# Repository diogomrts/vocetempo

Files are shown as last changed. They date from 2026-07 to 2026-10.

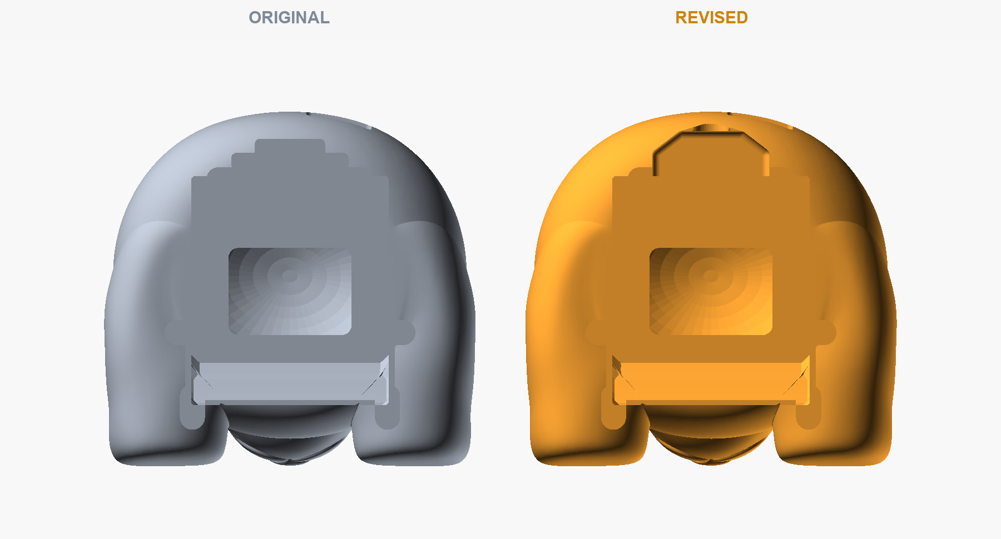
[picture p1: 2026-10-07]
enclosure/previews/joystick_bottom_views.png

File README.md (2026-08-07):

# Vocetempo

A standalone **talking bedside clock** built on an ESP32. It works completely
offline — no Wi-Fi, Bluetooth, internet, or phone required. It shows the time
on an OLED and speaks it aloud, automatically at configurable intervals or
on demand with a button.

> The name blends Italian _voce_ (voice) with _tempo_ (time), rooted in the
> Latin _vox_ + _tempus_.

## Features (v1)

- Large clock display (HH:MM), date, and weekday on a 2.42" OLED.
- Spoken time on demand and automatically (hourly / 30 min / 15 min).
- Single-thumbstick control, so the whole UI can be found by feel in the dark.
- Quiet hours: silence automatic announcements overnight (manual still works).
- Automatic daylight saving: pick your region once and the clock adjusts itself
  twice a year, entirely offline. Off by default.
- Fully on-device configuration; settings persist in flash.
- Modular speech clips for compact storage and easy future languages.

## Daylight saving

Under **Settings → Summer time**, choosing a region makes the clock change
itself on the right night, with no internet and nothing to maintain: every
region below switches on an algorithmic rule ("last Sunday in March"), so the
dates are computed on-device and stay correct indefinitely.

| Setting | Region |
| --- | --- |
| `Off` | no daylight saving (default) |
| `UK/Portugal`  | UK, Ireland, Portugal, Canary Islands |
| `Europe CET` | Spain, France, Germany, Italy, Poland, … |
| `Europe EET` | Greece, Finland, Romania, the Baltics |
| `USA/Canada` | all US and Canadian zones |
| `Chile` | Chile |
| `Australia SE` | NSW, Victoria, South Australia, Tasmania, ACT |
| `New Zealand`  | New Zealand |

Leave it `Off` for anywhere that no longer observes DST, including Brazil,
Argentina, most of Mexico, Russia, Turkey, India, China and Japan.

Choosing a region never changes the time on screen — only what happens on the
transition nights from then on. It can be set at any point, before or after
setting the clock, and in any month.

Internally the DS3231 stores **standard (winter) time** and is never rewritten
for a transition, so the hardware keeps ticking undisturbed; the offset is
applied when the time is read.

## Hardware

- DollaTek ESP32 dev board (ESP-WROOM-32, CP2102, USB-C)
- Hailege 2.42" SSD1309 128x64 OLED (I2C)
- DollaTek DS3231 RTC (I2C)
- DFPlayer Mini + microSDHC (audio)
- CQRobot 3W 4ohm speaker
- KY-023 analog joystick (up/down, left = back, right or click = OK)
- 5V USB wall power

See [`docs/PLAN.md`](docs/PLAN.md) for the staged roadmap,
[`docs/WIRING.md`](docs/WIRING.md) for the pin-by-pin wiring, and
[`docs/ASSEMBLY.md`](docs/ASSEMBLY.md) for soldering and enclosure assembly.

## Toolchain

- [PlatformIO](https://platformio.org/) with the Arduino framework for ESP32.
- Board environment: `esp32dev`.

## Build & upload

```sh
# Build
pio run

# Upload to the connected board
pio run --target upload

# Open the serial monitor (115200 baud)
pio device monitor

# Run the unit tests on your computer (no board required)
pio test -e native
```

The `native` test environment builds only the hardware-free logic — the
daylight-saving rules and the announcement scheduler — so both can be verified
on the host without waiting for a transition night.

## Status

**Stage 1 of 12** — verifying ESP32 programming with a serial "Hello"
heartbeat and onboard LED blink. Hardware peripherals are added one stage at a
time; see the roadmap in `docs/PLAN.md`.

## License

MIT — see [`LICENSE`](LICENSE).

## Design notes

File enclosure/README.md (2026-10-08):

# Vocetempo enclosure

Parametric 3D-printable enclosure for the panda-themed talking clock, written in
[OpenSCAD](https://openscad.org). The electronics live in a **slide-out cage**
that drops into a hollowed panda figurine from below, so the panda never has to
be opened to service the clock.

**Current body: v8, 217.4 mm tall (108.7% of the original sculpt).** The cage,
cavity and hardware cuts remain at their original size and position. Use the
new `joy_cap_scaled_body.stl` with this body; the original cap is too short.
Print the exports at **100% in the slicer** — do not scale the completed STL.

The latest two-colour version is
[`3mf/panda_colored_final.3mf`](3mf/panda_colored_final.3mf).
The saved [`full` project](3mf/panda_body_uniform_v8_black_white_full.3mf) has
identical geometry and painting; the final file packages its mesh in one model entry.
Open it **as a project** in Bambu Studio / OrcaSlicer to retain the painting:
filament 1 is white and filament 2 is black. Select your actual printer, material
and print profiles before slicing; the file is an unsliced painted model.
The original 500,162 triangles and all v8 cutouts are unchanged. Black covers
the ears, eye patches/eyes, nose, arms/shoulder band and feet. The colour data
survived a Bambu Studio 2.8.2.61 import/export check without changes.
The complete surface revision wraps the black feet around both full soles,
connects both arms continuously into the back band, and paints the ear vent bore
walls black. Fine paint boundaries follow the sculpted seams. The internal cage
and mounting surfaces remain white; the physical mesh is unchanged.
See the [six-angle full-body preview](previews/panda_body_v8_paint_full_views.png),
[360-degree view](previews/panda_body_v8_paint_full_turntable.gif),
[underside and arm comparison](previews/panda_body_v8_paint_full_comparison.png),
and [original painting report](previews/panda_body_v8_paint_full_checks.txt).
The latest saved projects include additional paint touch-ups on 3,796 triangles;
they preserve the approved v8 geometry within native-save rounding (under 0.0001 mm).
See the [saved-project audit](previews/panda_body_v8_saved_projects_checks.txt)
for current file hashes and the final Bambu Studio round-trip check.
The [previous precision painting](3mf/panda_body_uniform_v8_black_white_precision.3mf),
[detailed painting](3mf/panda_body_uniform_v8_black_white_detailed.3mf), and
[first painted version](3mf/panda_body_uniform_v8_black_white.3mf) are retained.

## Files

| File | Purpose |
| ---- | --- |
| `dimensions.scad` | Every component measurement + design decision, in ONE place. **Edit here.** |
| `helpers.scad` | Shared shape modules (rounded box, screw boss, etc.). |
| `cage.scad` | The electronics cage - the real mechanical part. Print-ready. |
| `panda.scad` | The panda body: uniformly enlarges the original sculpt, then applies fixed-size hardware cuts. |
| `expand_rump.py` | Historical v5 local deformation generator; no longer used by the current body. |
| `fitcheck.scad` | Seats the cage in the body (ghost / section / breach modes). |
| `layout_walls.scad` | 2D map of all four mounting walls, unrolled (collision check). Includes `cage.scad`, so it cannot drift from the geometry. |
| `render_previews.sh` | Renders `previews/*.png`. |
| `verify_window.py` | Blender check: pixel coverage of the OLED window + exactly where its cut lands on the sculpt. Run it after touching `oled_win_*`. |
| `verify_cage.py` | Ray-casts the exported cage and asserts every mount is real: bosses on flat wall, OLED envelope clear, joystick standoffs proud of the back wall, base open, cover ledge present. Run it after touching any mount. |
| `verify_joystick_channel.py` | Checks the exported body against the printed cage, the joystick's full insertion sweep (including bare shaft and bent header), and the remaining rear wall. |
| `verify_entrance.py` | Checks the entrance against 353 cage positions and verifies that the local repair preserves the rest of the body and magnet supports. Reports higher corner interference separately. |
| `verify_rear_cover.py` | Historical v4/v5 rear-cover checks; not applicable to the uniformly scaled v6/v7 bodies. |
| `verify_assembly_alignment.py` | Audits actual OLED sight lines, speaker aperture/connected sound path/all 26 ear vents, USB alignment, unchanged cage geometry and the v8 internal-only correction. |
| `verify_uniform_body.py` | Checks exact uniform scaling, fixed hardware clearances, magnet supports, cage insertion and the longer cap at both PCB spacings/socket orientations. |
| `probe_skin.py` | Where the sculpt's belly surface is at any (X, Z). |
| `probe_env.py` | Belly / rump / half-width envelope per height - how big a box fits. |
| `fit_shell.py` | **Solves** `shell_prof` against the sculpt. Re-run after changing `cage_w`, `cage_d`, `cage_yfront`, `cage_z0` or `cage_h`. |
| `refit.py` | Derives EVERY host-dependent constant in one pass - the transform, `shell_prof`, the OLED and joystick placements, the head/neck/ear survey, the magnet check. Run it after swapping the sculpt or resizing the box. |
| `scale_sweep.py` | Host height vs every gate. This is the table that chose 200 mm. |
| `compare_mesh.py` | Diffs two sculpts (size, shape, where the surfaces moved). |

The Python tools need `numpy` (`verify_window.py` needs Blender). Every tool
reproduces `panda_raw()`'s frame exactly, so their numbers paste straight into
`dimensions.scad`.

## The cage (`cage.scad`)

A box, 75 (W) x 80 (H) x 88 (D) mm, open at the base (the "service side").
Its cross-section (defined by `shell_prof` in `dimensions.scad`) is a rectangle
whose FRONT FACE can be set back per height and whose CORNERS can be chamfered per
height. It stays flat, full and forward through the whole board-mounting zone - so
every module's bosses land on a real, flat wall - and only moves where there are no
features: the base fillet, the paw crests, and the shoulders. That is how it follows
the round panda without either spearing its corners through the skin OR moving the
walls away from the mounting bosses. On this host the `breach` fit-check renders
**completely empty**, and the cage-inside-body collision check has zero volume.

- **Front face:** the OLED window (the true 55 x 28 lit area, offset +3.1 mm up)
  and **nothing else**. The PCB is 68.63 x 46.60 and even 88 mm of depth does not
  make room for a second device on this wall.
- **Back wall:** the **joystick**, bolted to four standoffs on the wall's OUTER
  face; the DFPlayer lower-right and the USB-C exit slot lower-left, inside.
- **Side walls:** ESP32 (left, portrait, USB-C edge down); RTC (right, on its 3
  real holes). The corner chamfers never cut a side face (`cf` peaks at 1.92), so
  a side wall is full-depth through the whole board zone.
- **Top face:** stadium-shaped throat firing UP into the panda's head (the head
  is the acoustic resonator); four bosses for the boxed speaker's ears.
- **Base:** an outward flange with 4 magnet pockets (retains the cage in the
  body), a ledge round the inside of the walls, and a screw-on **base cover**.

### The joystick bolts to the OUTSIDE of the back wall

It is on the rump, not the belly: the OLED alone is 46.6 mm tall and the KY-023
adds another 26.7 plus clearance, which no front wall this sculpt offers can hold.

*How* it mounts changed with the re-fit. It used to drop into a pocket in a
thickened plinth inside the back wall, with the gimbal poking out through a bore and
a separate printed frame clamping the PCB down - all of that existed because the
module's own mounting holes (19.85 x 19.80) sit right on the edge of the bore the
gimbal (19.80 x 23.40) needs, so a boss there loses over half its section.

Turning the module round deletes the problem. With the PCB on standoffs on the
wall's OUTER face and the gimbal pointing away into the rump there is no bore, no
pocket, no plinth and no frame; the only thing that crosses the wall is five wires.
It also uses the module's own four holes, which is what they are for. Fit it before
the cage goes into the panda - the screws come from the rump side.

The cost is depth. Measured out from the cage's back face at panda Y-43:

```
 2.00  standoff
 0.92  PCB
11.76  gimbal body
14.68  proud of the wall  (the rump is 25.7 mm deep here, leaving 11.0 for the cap)
```

The rump has a **continuous insertion channel**, wide enough for the PCB and bent
header near the cage and narrowing toward the gimbal. The printed **stalk cap**
spans the remaining 11 mm to the surface and is fitted only after insertion.

### Assembly relief v2, 2026-10-07

The physical assembly needs more room than the original nominal clearance check
suggested. The joystick is mounted sideways, and the **left side when looking
straight into the panda's back** needs the deeper recess all the way across.
That side is **panda -X**. The first comparison's simplified hardware overlay
omitted the side projection and assumed the recorded 2 mm PCB stand-off; it must
not be used as a measurement of the assembled device.

The v2 body adds another **3 mm of depth beyond the first relief**, keeps the
channel **10 mm taller than the original**, and preserves the printed cage,
cover, cap bore, magnet seats and mounting locations:

- Main gimbal limit **Y-64.5**: **21.5 mm behind the cage wall**, 6 mm deeper than
  the original channel and 3 mm deeper than v1.
- PCB/header shoulders also gain **another 3 mm**, to Y-51 and Y-57.5.
- Bare-shaft groove **Y-67.43**: **24.43 mm behind the cage wall**, another 3 mm
  beyond v1. This allows 3 mm extra PCB spacing while keeping 0.8 mm beyond the
  recorded shaft tip.
- A **broad left recess** extends to X-22.9 and Y-64.5 through Z55. Above that it
  slopes inward with the narrowing rear skin and joins the **3 mm rounded roof**
  at Z75.35. Its 2 mm side corner radii avoid sharp notch corners.
- The continuous underside opening reaches approximately **Z19.2 mm**. The wall
  tapers above the opening; over Z25..75.35 the 0.5 mm inspection grid measured a
  minimum **1.06 mm** to the outside skin. The USB and cap holes are excluded.
  The user explicitly accepted a thinner rear wall for this clearance revision.

The export is one closed, consistently oriented solid. Checks pass for the
printed cage and the full insertion sweep with **3 mm extra PCB stand-off**, both
in-plane PCB/gimbal orientations, the bare shaft, both header directions and an
additional bulky left-side allowance. No unintended rear openings were found
above the entrance. These are geometric allowances, not confirmation of the
unmeasured assembly or a material-strength simulation.

Check the preserved v2 export from this directory:

```sh
# Requires numpy, trimesh, manifold3d, scipy and rtree:
python verify_joystick_channel.py stl/panda_body_joystick_relief_v2.stl
```

`stl/panda_body_joystick_relief_v2.stl` preserves the approved joystick revision.
The latest body adds the entrance fix and smooth rump expansion below. The original and first relief are
retained in `stl/previous/`.
See `previews/joystick_bottom_comparison_v2.png` for the actual channel profiles;
the blue line marks v1. Earlier comparison images are historical v1 views.

### Entrance relief v3, 2026-10-07

The printed cage caught a sharp lip between the feet. The old body cavity copied
the cage's narrowed base section, even though the wider upper cage wall must pass
that same height. At Z7.1 the lip projected about **1.8 mm into the insertion
path**. V3 removes it and adds a front-only **0.8 mm lead-in bevel**, tapering to
the existing front clearance at the flange seat, Z11.2.

Only 0.381 cm³ is removed, entirely within the front entrance below Z11.25.
The magnet pockets/supports, flange seat, OLED opening and joystick v2 geometry
are unchanged; none of the already-printed cage parts needs replacing. The
export is one closed solid. At 353 cage positions spaced 0.25 mm apart, entrance
overlap falls from 103.588 mm³ to zero. The seated cage and all joystick checks
also pass. See `previews/entrance_comparison_v3.png` and the accompanying check
reports.

**Scope limit:** the higher corner ridges beside the paws remain. Removing their
entire insertion envelope would open holes in the outer wall. A perfectly
straight full-body insertion still has up to 5.777 mm³ overlap there, unchanged
by this local repair. V3 fixes the reported entrance obstruction; it is not a
guarantee of a completely interference-free physical assembly.

`stl/panda_body_entrance_relief_v3.stl` preserves this revision for comparison.

```sh
python verify_entrance.py stl/panda_body_entrance_relief_v3.stl --baseline stl/panda_body_joystick_relief_v2.stl
```

### Reduced uniform enlargement v7, 2026-10-08

V7 reduces the body enlargement from **15% to 8.7%**, keeping the whole original
sculpt uniformly scaled about the ground-plane origin. Its round proportions are
unchanged. Overall size is **157.280 × 150.182 × 217.4 mm (W/D/H)**, down from
166.396 × 158.886 × 230 mm in v6. `panda_body_scale` controls only the body blank;
`panda_h`, `panda_raw()` and the original skin reference stay at 200 mm for the
already-printed cage and base cover.

**The lower-left notch corner sets the minimum scale.** With the fixed notch and
original outside shape, 108.7% leaves a minimum sampled wall of **1.019 mm** above
the underside flange seat at Z11.2. At 108.6% it drops to 0.976 mm. This is the
smallest tested scale in 0.1% increments that retains a 1 mm wall there. The
nearest-surface check covers 20,836 points, with 0.05 mm spacing along the limiting
lower edge; intentional USB and cap openings are excluded. This is a geometric
thickness measurement, not a material-strength guarantee. The wall higher up is
thicker because the unchanged notch and original outer curve are different
shapes; above Z25 its minimum is 6.667 mm, reduced from 10.538 mm in v6.

The cage cavity, v2 deep left joystick channel, v3 entrance lead-in, screen window,
14 mm cap bore, USB cutter, flange seat and magnet pockets keep their sizes and
coordinates. The sound chamber and ear vents follow the enlarged head; overlapping
original/scaled chimney sections join them to the fixed speaker position. The
screen is more recessed than on the original body, but less than in v6. The
underside remains open for cage insertion.

**Reprint the body and the matching `joy_cap_scaled_body` cap.** The back at the
cap centre is now 6.18 mm farther out than the original. The v7 cap has a **20 mm
stalk and 4 mm neck**, shortened from v6's 24 mm stalk; it retains the same keyed
socket and 16 mm thumb pad. It clears the unchanged bore in both socket
orientations, nominal and +3 mm PCB spacing, 0–11° tilt in 15° azimuth increments
(1,152 poses), also with a 10% radial size allowance. Print the neck solid and
check fit/movement before gluing. The cage, cover and retention bars are unchanged.

Validation: one connected closed body; the blank exactly matches the uniformly
scaled original; all fixed hardware cutters are clear; all four magnet supports
remain intact. The cage seats without collision and the repaired feet entrance
clears at 353 insertion positions. The existing **5.777 mm³ higher front-corner
interference remains**, so this is not a physical friction-free fit certification.
The PCB, sideways gimbal, bare shaft and both header orientations pass the existing
insertion-envelope checks, including the requested extra 3 mm PCB spacing.

**Latest body: `stl/panda_body_uniform_v8.stl`.** `panda_body.stl` and
`panda_body_joystick_relief.stl` are identical copies. The matching cap is
`stl/joy_cap_uniform_v7.stl`, also copied to `joy_cap_scaled_body.stl`.
`stl/Archive.zip` contains the current body, matching cap, unchanged cage/cover/bars
and printing notes. Slice these at **100%** to preserve the unscaled cavity;
217.4 mm usable print height is needed, plus any raft.

See `previews/uniform_body_comparison_v7.png` for original/v6/v7 size comparison
and `previews/uniform_body_section_v7.png` for the thinner rear-wall section.
Reports are `previews/uniform_body_v7_*checks.txt`.

```sh
# OpenSCAD Manifold; Python checks need numpy/trimesh/manifold3d/scipy/rtree.
openscad --backend=Manifold --export-format binstl -o stl/panda_body.stl panda.scad
openscad --backend=Manifold -D 'part="joy_cap_scaled_body"' -o stl/joy_cap_scaled_body.stl cage.scad
openscad --backend=Manifold -D 'mode="body_blank"' -o /tmp/blank.stl fitcheck.scad
openscad --backend=Manifold -D 'mode="hardware_void"' -o /tmp/hardware_void.stl fitcheck.scad
openscad --backend=Manifold -D 'mode="joystick_void"' -o /tmp/channel.stl fitcheck.scad
openscad --backend=Manifold -D 'mode="usb_void"' -o /tmp/usb.stl fitcheck.scad
python verify_uniform_body.py stl/panda_body.stl --scale 1.087 --channel /tmp/channel.stl --usb /tmp/usb.stl --blank /tmp/blank.stl --hardware-void /tmp/hardware_void.stl --cap stl/joy_cap_scaled_body.stl --baseline stl/panda_body_entrance_relief_v3.stl
python verify_joystick_channel.py stl/panda_body.stl --skin /tmp/blank.stl
```

Previous versioned bodies, caps and previews are retained for comparison. V4's
cover and v5's local rump deformation were rejected aesthetically; v6's uniform
115% enlargement was too large. The v5 generator/source pair is no longer used
by `panda.scad`. The original `joy_cap` remains available for 200 mm bodies.
Print exports and ZIPs stay local under the existing ignore rule.

### Assembly alignment audit / speaker inlet v8, 2026-10-08

V8 keeps v7's **108.7% sculpt, 217.4 mm height, 1.019 mm minimum notch wall,
fixed cage cavity and same cap**. A full export audit found that the speaker's
cage opening is centred at panda Y-7 (the cage speaker is shifted 8 mm), while
the neck chimney is centred near Y1. A 3.208 mm rear strip of the throat therefore
met body material immediately above the cage roof: 142.541 mm³ of obstruction
inside the exported throat cutter.

`panda_speaker_inlet()` now clears the whole opening through the roof and blends
it into the existing neck chimney. The speaker offset is shared in
`dimensions.scad` so the two parts cannot drift. It removes **580.715 mm³** of
internal plastic; the change stays at least **37.938 mm inside the outer skin**.
Nothing is added, and no external shape, electronics placement, magnet seat,
OLED/joystick/USB cut or cage geometry changes. The printed cage and v7 cap remain
usable; the body is the only updated print file.

The audit verifies:

- Current cage source versus already-printed `cage.stl`: **zero geometric change**.
  OLED, speaker and joystick bosses/pilots, base ledge and side-board mounts pass
  `verify_cage.py`.
- OLED: 55.4 × 28.4 mm body opening, centred X0/Z47.8; all 8,192 pixel sight lines
  clear the cage. The body shows **8,188**, with the same four extreme corner
  pixels masked by its original 2 mm corner radii.
- Speaker: full offset cage throat clear, connected inlet/chimney/head chamber,
  **all 26 ear vents open to the exterior**. Acoustic loudness/resonance has not
  been measured on a physical print.
- Joystick: fixed 14 mm bore at X0/Z50; sideways PCB/gimbal/header and bare-shaft
  insertion envelopes pass, including +3 mm PCB spacing and the deep left recess.
  The unchanged v7 20 mm cap passes all **1,152** movement poses.
- USB: both body and cage slots clear all **589** access-ray samples.
- Cage seating, four magnet supports, thin notch wall and repaired entrance still
  pass. The existing higher front-corner insertion interference remains unchanged.

Reports: `previews/assembly_v8_checks.txt`, `assembly_v8_cage_checks.txt`,
`assembly_v8_uniform_checks.txt` and `assembly_v8_joystick_checks.txt`.

```sh
openscad --backend=Manifold -D 'part="cage"' -o /tmp/cage-current.stl cage.scad
openscad --backend=Manifold -D 'mode="speaker_void"' -o /tmp/speaker.stl fitcheck.scad
openscad --backend=Manifold -D 'mode="speaker_inlet"' -o /tmp/inlet.stl fitcheck.scad
openscad --backend=Manifold -D 'mode="acoustic_void"' -o /tmp/acoustic.stl fitcheck.scad
python verify_cage.py stl/cage.stl
# /tmp/blank.stl comes from the body_blank export above.
python verify_assembly_alignment.py stl/panda_body.stl --baseline stl/panda_body_uniform_v7.stl --blank /tmp/blank.stl --cage-source /tmp/cage-current.stl --speaker /tmp/speaker.stl --acoustic /tmp/acoustic.stl --inlet /tmp/inlet.stl
```

### Printable parts (via the `part` selector at the bottom of `cage.scad`)

```sh
openscad --backend=Manifold -o stl/cage.stl      -D 'part="cage"'      cage.scad
openscad --backend=Manifold -o stl/cover.stl     -D 'part="cover"'     cage.scad
openscad -o stl/esp32_bar.stl -D 'part="esp32_bar"' cage.scad
openscad -o stl/dfp_bar.stl   -D 'part="dfp_bar"'   cage.scad
openscad -o stl/joy_cap_scaled_body.stl -D 'part="joy_cap_scaled_body"' cage.scad # current 217.4mm body
openscad -o stl/joy_cap.stl -D 'part="joy_cap"' cage.scad # historical 200mm body only
```

`cage` and `cover` need **Manifold**: both clip themselves to the panda mesh (the
cage's upper shell to the eroded skin, the cover to the sculpt's domed base). There
is no `joy_frame` any more.

Then check it:

```sh
python verify_cage.py stl/cage.stl
```

## Original 200 mm reference and design history

The following measurements describe the **200 mm reference used by the cage**.
The current v8 outer body is separately enlarged to 217.4 mm as described above.

`panda/panda_original_without_embosses.stl` removes the sculpt's embossed screen
plaque and belly knob, so openings no longer have to land on a sculpted feature.
It is the host, at **200 mm** tall. Both changes landed together, because they had
to: the replacement is a different size and shape, not the same mesh with two bumps
shaved off, and at 160 mm it did not fit the electronics at all.

| | old | de-embossed |
| --- | --- | --- |
| raw Z span | 0.95893 | 0.93937 (2% shorter) |
| raw Y span | 0.70079 | 0.64892 (7% shallower) |
| raw X | 0.44 mm off-centre | symmetric |
| belly @ the screen, X0 | plaque | smooth, no feature to key off |

The transform is now **derived from the mesh** rather than hand-fitted, so swapping
the sculpt again changes two constants instead of the whole design:

```
panda_scale   212.9096      (= 200 / 0.93937 raw Z span; was a hand-fitted 166.7)
panda_y_off     9.036       (was a hand-fitted 26)
panda_x_off     0           (this mesh is symmetric)
```

`refit.py` prints the entire constant set for a given host in one pass, and every
number in `dimensions.scad` that depends on the sculpt came from it.

### What 200 mm buys, and what it does not

The parts do not scale - a 2.42" OLED is 68.63 x 46.60 whatever size the panda is -
so the host's size *is* the clearance budget. `scale_sweep.py` sweeps it:

```
panda_h | yfront | cage_d | plate band (cage Z) | top setback | recess | rump
    160 |   36.0 |   70.4 |   2.0.. 32.0 =  30.0 !|      7.9   |   12.6 |  19.9
    180 |   40.5 |   79.2 |   2.0.. 36.0 =  34.0 !|     17.9   |   14.4 |  22.8
    190 |   42.8 |   83.6 |   2.0.. 38.0 =  36.0 !|     19.8   |   15.2 |  24.2
    200 |   45.0 |   88.0 |   2.0.. 62.0 =  60.0  |     16.2   |   15.7 |  25.7
    210 |   47.2 |   92.4 |   2.0.. 66.0 =  64.0  |     12.7   |   16.1 |  27.1
! = the front plate is shorter than the OLED's 46.6mm PCB, so the screen cannot mount
```

200 is the smallest host where the front plate is long enough to hang the screen on.
Below it the plate collapses to ~30-36 mm against the 46.6 the PCB needs.

It also unpicks the deadlock that stopped the re-fit landing for a session. At 160
`cage_h` had exactly one legal value with 0.8 mm to spare - the belly pinched at
panda Z72, capping it at 64, against the 61.2 mm (`cover_ledge_h` 6 + margin 2 +
`esp_w` 53.2) a portrait ESP32 needs - and at that height the ESP32's USB-C mouth
landed on the cover ledge, so a straight plug was impossible and the panel-mount
port became mandatory. At 200 the box is 80 tall, the interior is 78, and
`6 + 2 + 16 (straight plug) + 53.2 = 77.2` fits with 0.8 to spare. The panel-mount
port is optional again.

What it does **not** fix is the screen recess, and that is permanent:

```
lateral belly drop from X0 out to |X|35.5, i.e. across the OLED's own width
  panda_h 160:  3.5mm @Z26   7.7mm @Z38   4.3mm @Z50
  panda_h 200:  4.4mm @Z33  10.1mm @Z48   5.4mm @Z63
```

A flat 68.63 mm-wide board can only come as close as the NARROWEST point across its
own width, and that drop grows with scale at about the same rate as the belly moves
forward. The landed figure is **15.7 mm** with `so_h_oled` 7, or **10.7 mm** if the
left-edge header is desoldered and it drops to 2. ~11 mm is the floor for this board
on this belly at any scale; only a narrower display changes it.

### The front wall steps back (`shell_prof`'s fourth column)

With a **single-plane** front wall, cage height and screen depth fight each other
directly, because the plane has to clear the arm pinch at the very top:

```
panda_h 200, max flat-front Y vs how high the cage reaches
  top at panda Z74 -> yfront 41.6      top at Z80 -> 33.7      top at Z86 -> 29.6
```

A cage tall enough for the ESP32 would therefore drag the front wall back to Y29.6
and bury the screen ~31 mm deep. `shell_prof` now carries a per-height FRONT SETBACK
(`fyb`, the fourth column) so the front plate holds Y45 through the OLED's whole span
and steps back only above the arms - 0 up to cage Z62, then 0.86 -> 16.57 by the top.
That is the change that lets the screen and the ESP32 both fit. `shell_section()` in
`helpers.scad` already took an `fyb` argument; `shell_stack()` and `prof_fyb()` pass
it through.

A second consequence: on this host `cb` is **0 at every height**, so the back wall is
full width for the first time and the joystick, the DFPlayer and the USB exit share
an uncramped 71 mm.

`PANDA_STL=panda/panda_original.stl python fit_shell.py` switches the tools back to
the old sculpt for comparison.

## The panda body (`panda.scad`)

Imports the sculpt **untouched**, hollows only where the cage sits, and cuts the
OLED window (belly), the joystick cap bore + continuous insertion channel (rump), the
**USB-C exit** (rump), the speaker chimney into the hollow head, the ear grilles,
and the base hatch/rebate. Needs the **Manifold** backend (`--backend=Manifold`);
the 500k-triangle mesh is far too slow for CGAL.

Three things about this host are worth knowing before editing it:

- **The base is domed.** Its lowest points are the outer edges of the feet at
  |X|~40 (panda Z0.5); at X0 the body does not start until Z~1.5, and at Z2 the
  silhouette has already tucked back to Y40.3 at X0 and Y28.7 at |X|34. That is why
  `cage_z0` is 7, why the base flange's front rim is a *pull* rather than a reach,
  and why the base cover is intersected with the sculpt instead of being a flat
  plate (it would otherwise stand up to 14 mm proud of the belly).
- **The joystick channel opens through the underside.** V2/V3 also broke through
  the rear skin up to about Z19.2. V5 expands the original rump to close the rear breakout while
  preserving the underside entrance and the entire insertion channel.
- **Y coordinates do not scale with the host.** X and Z do, but `panda_y_off` moved
  when the transform stopped being hand-fitted, so anything hard-coded in Y - the
  head cavity centre, the ear plenum and ducts, the skin-erosion axis - has to be
  re-measured, not rescaled. Rescaling puts the ear plenum 20 mm outside the mesh.

The original sculpt is never edited in place. V5 generates a derived outer sculpt
with a smooth local expansion before the functional openings are subtracted.

### There is no colour split, on purpose

`panda.scad` used to have a `colored_3mf` mode that carved the classic black/white
panda markings out of the body with boxes, spheres and prisms and exported them as
two shells for a multi-material slicer. **It has been removed.**

The markings are curved features that follow the surface, and they are simply not
describable by primitives. Intersecting the body with analytic solids gives
boundaries that cut *across* the sculpted shapes instead of along them - straight
lines where the arm meets the chest, and eye patches that either spill past the
sculpted almond or shrink to the pupil depending on how the curved face happens to
slice the solid. No amount of tuning the numbers fixes that, and the numbers had to
be re-guessed on every host change because they were pure eyeballing.

The current two-colour 3MF linked above uses native slicer surface painting on
the unchanged mesh. The arm and paw boundaries follow recessed sculpted seams;
the rear shoulder band uses a smooth painted boundary. No colour solids are
subtracted from or added to the body.

## The OLED window (and the paws it no longer cuts)

**Requirement: every one of the 128×64 pixels must be visible.** So the window is
the full lit area + `fit_gap` (`oled_win_w × oled_win_h` = 55.4 × 28.4 mm), and the
sculpt's folded paws are allowed to be cut through if they stand in the way.

At 160 mm they did: the cut took **8.1 mm off each paw** over Z42–58 and the arms
ended abruptly at the screen. **On the 200 mm host they do not.** The paws are 25%
further apart - their inboard edges are at |X|29.5 at panda Z40 and |X|35.5 at Z47.8
against the window's 27.7 - so the arms stay exactly as sculpted.

Verify with:

```sh
cd enclosure && blender -b -P verify_window.py
```

which checks pixel coverage and reports exactly where the cut lands. Current result:
**8188 of 8192 lit pixels visible**, both corner icons on screen, **0.00 mm into the
paws**, 0.00 mm into the shoulder, 0.83 mm into the feet.

### The corner radius is the one real knob

It trades corner pixels against the feet, whose top-inner corners are the only thing
the window still touches. The table below was measured at 160 mm, where the bite was
about 2.5× what it is now:

| `oled_win_r` | lit px hidden | corner icons | bite into the feet |
| --- | --- | --- | --- |
| **2.0 mm** (current) | **4 / 8192** | both survive | 2.1 mm at Z32–35 |
| 4.0 mm | 48 | both clipped | 1.1 mm |
| 6.0 mm | 120 | both clipped | 0.04 mm |
| 8.0 mm | 236 | both clipped | none |

r = 2.0 is chosen because the requirement is all pixels: it hides one pixel per
corner and keeps the quiet-hours and mute icons, which live in the top corners, on
screen. The price on the 200 mm host is a **0.83 mm** nick in each foot's top-inner
corner.

### What was rejected

All of these were built and measured:

- **Sizing the window to the sculpt's own embossed screen plaque** (36 × 21 mm, its
  raised frame becoming the bezel). Geometrically perfect — nothing trimmed or
  deformed, rim on flat plaque to ±0.15 mm — but it exposes only an 84 × 48 safe area,
  hiding a third of the panel. Rejected on the pixel requirement, and moot now: the
  host is the de-embossed sculpt, which has no plaque.
- **Countersinking the window** (`oled_bevel_*`) — two flat "wings" beside the screen
  ending in a hard crescent line.
- **A rolling-ball paw trim** (`arm_trim()`) — rolled the sculpted paw tip into a
  spherical dome and planed its crest.
- **Swinging the arms outboard in Blender first** (`panda_arms.py`). This *did* free
  the paws and keep them fully rounded, clearing this exact window with a 1.3–2.1 mm
  bezel. But there are only **2.6 mm** of surface between the paw's underside (Z42)
  and the top of the feet (Z39.4), so the swing's taper either tore a serrated ridge
  across the belly or sheared the leg tops into **pointy tips**. The best of ~30 swept
  configurations still rotated the legs 13 mm and visibly widened the stance, and left
  only 1.3 mm of bezel on the −X side (the sculpt's paws are not symmetric). A
  biharmonic thin-plate solve was **20× worse** (3,600 new creases vs 149), because
  the sculpt's triangulation (21:1 edge lengths, 19% negative cotangent weights) is
  far too irregular for a Laplacian method. Rejected as costing more than the paw cut
  it was avoiding.
- **A smaller 1.54" 128×64 panel** (~35 × 17.5 mm active) would fit the plaque
  entirely — all pixels, panda untouched, no firmware change — but needs a different
  module, a new cage OLED mount, and gives a much smaller clock. Worth revisiting if
  the sliced paws ever grate.

## Rendering previews

```sh
brew install --cask openscad      # once
cd enclosure
./render_previews.sh              # writes previews/*.png
```

Or open `cage.scad` in the OpenSCAD GUI and press F5 (preview) / F6 (render).

## Fit-check (does the cage fit inside the panda?)

`fitcheck.scad` seats the cage inside the hollowed body. Its `breach` mode outputs
ONLY the cage material sticking OUT of the panda - it should be effectively empty:

```sh
# should render to NOTHING; any solid at all = the cage breaches the skin
openscad --backend=Manifold -o /tmp/breach.stl -D 'mode="breach"' fitcheck.scad
openscad --backend=Manifold -D 'mode="ghost"'   fitcheck.scad   # visual overlay
openscad --backend=Manifold -D 'mode="section"' fitcheck.scad   # X=0 cross-section
```

The cage cross-section (`shell_prof`, 88 mm depth, per-height front setback plus
corner relief) is **solved** against a rasterisation of the raw skin - not tuned -
so every point of every section stays 1.6 mm inside the surface. On this host the
breach renders completely empty, where the old one left a 0.27 mm speck.

Worth knowing: intersecting the placed cage with the finished body is *not* empty,
but its volume is exactly 0 - the facets it produces are the flange's top face lying
on the rebate ceiling (they are meant to touch) and the eroded-skin surface both the
cage and the cavity are clipped to. Check the volume, not the facet count.

Separately, `part="cage"` clips every mounting boss to the shell, so no standoff
can float outside or poke through a wall (this was a real earlier bug). The board
zone is kept flat-walled so all of a board's standoffs stay the same height.

## Measurements

The numbers in `dimensions.scad` are **measured from the actual boards** (see
`docs/MEASUREMENTS.md` for the method and values). A few remain nominal / TODO
(noted inline) - the RTC exact hole positions were read from a photo and should
be caliper-confirmed if the fit is tight.

## Serviceability (baked into the design)

- **Slide-out cage:** all electronics on one cage that enters from the base;
  pull it out to service anything. Retained by 4 magnet pairs (~8 N vs ~2 N
  weight).
- **SD card & USB-C** point at the open base / back slot, reachable without
  opening the shell. At 200 mm a straight USB-C plug fits, so the panel-mount
  port is an upgrade rather than a requirement.
- **The joystick comes off with four screws** from the rump side - no frame, no
  pocket, no bore to line up.
- **No perfboard:** modules screw directly to printed standoffs/bosses (ESP32 &
  DFPlayer, which lack holes, use screwed retention bars). Wired point-to-point.

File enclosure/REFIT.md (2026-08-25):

# Re-fit spec: 200 mm host, de-embossed sculpt

> **LANDED 2026-08-21.** Sections 1-6 below are implemented in `dimensions.scad`,
> `panda.scad`, `cage.scad` and `helpers.scad`; the tools now default to this host,
> `verify_cage.py` and `verify_window.py` are green, and the `breach` fit-check
> renders empty. This file is kept as the derivation record. **Where it and the
> source disagree, the source is right** - see "Corrections found while applying it"
> at the bottom, which lists every place the spec turned out to be wrong or
> incomplete.

Every number here is solved against `panda/panda_original_without_embosses.stl` by
the tools in this directory (`refit.py`, `fit_shell.py`, `scale_sweep.py`,
`probe_skin.py`).

Re-derive any of it with:

```sh
python refit.py                     # full constant set for a given host
python scale_sweep.py               # host height vs every gate
PANDA_STL=panda/panda_original.stl python fit_shell.py   # compare to the old host
```

---

## 1. Host

```
panda_stl     = "panda/panda_original_without_embosses.stl"
panda_h       = 200
panda_scale   = 212.9087          # = 200 / 0.93937 raw Z span
panda_y_off   =   9.036           # panda_raw() translate; was a hand-fitted 26
panda_x_off   =   0               # this mesh is symmetric (the old one was 0.44 off)
```

`panda_raw()` becomes
`translate([0, panda_y_off, 0]) rotate([0,0,180]) scale(panda_scale) import(...)`,
which reproduces the frame every tool here uses: X centred, feet on Z0, belly at
+Y, Y bounding box centred on Y0.

## 2. Cage envelope

```
cage_w = 75      cage_h = 80      cage_d = 88      cage_z0 = 7
cage_yfront = 45                  -> cage_yc = 1
```

* `cage_h 80` gives 78 mm of interior. A portrait ESP32 needs 61.2, or 77.2 with a
  straight USB-C plug - so at 200 mm the straight plug fits and the panel-mount
  port goes back to being optional. At 160 mm only 62 mm was available, which is
  what deadlocked the whole layout.
* `cage_d 88` leaves 25.9 mm of rump and, critically, a real base rim for the
  magnets. Going deeper shortens the joystick stalk but eats that rim: at
  `cage_d 100` the rump is 13.9 mm but the hatch reaches within ~5 mm of the skin
  front and back.
* `cage_yfront 45` is the front PLATE position, held through the board zone by the
  new setback column (section 3).

## 3. shell_prof - now four columns

`[z, cf, cb, fyb]`. The 4th is a per-height FRONT SETBACK; `shell_section()` already
took an `fyb` argument, and `shell_stack()` + `prof_fyb()` now pass it through
(already committed in `helpers.scad`).

Without it, cage height and screen depth fight directly - a single front plane has
to clear the arm pinch at the very top, so a cage tall enough for the ESP32 (top at
panda Z87) drags the front back to Y29.6 and buries the screen ~31 mm deep.

```
shell_prof = [
  // z      cf      cb     fyb
  [  0.0,   0.00,   0.00,   2.22],
  [  2.0,   0.00,   0.00,   0.22],
  [  4.0,   0.00,   0.00,   0.00],
  [ 42.0,   0.00,   0.00,   0.00],   // ---- front plate at full Y45 ----
  [ 44.0,   1.52,   0.00,   0.00],
  [ 46.0,   1.81,   0.00,   0.11],
  [ 48.0,   0.00,   0.00,   0.00],
  [ 62.0,   0.00,   0.00,   0.00],   // ---- arms start to pinch above here ----
  [ 64.0,   0.00,   0.00,   0.86],
  [ 66.0,   0.00,   0.00,   2.58],
  [ 68.0,   0.00,   0.00,   4.49],
  [ 70.0,   0.00,   0.00,   7.15],
  [ 72.0,   0.00,   0.00,  10.04],
  [ 74.0,   1.91,   0.00,  12.40],
  [ 76.0,   1.91,   0.00,  13.76],
  [ 78.0,   1.92,   0.00,  15.16],
  [ 80.0,   1.92,   0.00,  16.57],
];
```

Rows between 4 and 42, and between 48 and 62, are all zeros - collapse them as
shown or write them out, the loft is linear either way. `cb` is **0 everywhere**,
so the back wall is full width for the first time: the joystick, the DFPlayer and
the USB exit all get an uncramped 71 mm to share.

## 4. Devices

```
dev_oled_pz = 47.8        OLED lit-window centre, panda Z
                          -> oled_cz 37.7, PCB spans cage Z14.4..61.0
                          -> bosses at cage Z16.2 and 59.2, both on flat wall
dev_joy_pz  = 50          joystick centre, panda Z, on the RUMP
so_h_oled   = 7           still clears both of the OLED's back headers
```

Screen recess is **15.7 mm** (10.7 if the left-edge OLED header is desoldered and
`so_h_oled` drops to 2). That is close to the floor for this display - see
`README.md`; a flat 68.63 mm board can only reach the narrowest point across its own
width, and that lateral belly drop is 4-10 mm at any scale.

### Joystick: change how it mounts

Move it from the pocket-and-frame arrangement to **standoffs on the OUTER face of
the back wall**, using the KY-023's own four holes. With the gimbal pointing away
from the wall there is no bore/boss conflict, so this deletes `joystick_plinth()`,
`joystick_pocket_cut()`, `joystick_bore_cut()`, `joystick_frame_bosses()` and the
whole `joy_frame` part. Only a small wire slot remains.

```
2 mm standoffs off the outer face -> PCB at panda Y-45, gimbal top at Y-57.68
rump skin at panda Z50 is Y-68.71   ->  joy_cap_stalk = 11.0
```

The rump insertion channel stays (the assembly now stands ~13 mm proud of the back
face instead of 9), and must clear the 32.3 mm PCB rather than the 24 mm gimbal.

## 5. Head, neck, ears

Both frames are the same mesh at different scales, so these scale linearly from the
values `refit.py` derived at 160 mm - multiply by **1.25**:

```
head_c   = [0, -5.0, 147.5]        head_r = [45.0, 37.5, 35.0]
sp_z0    = 75      sp_z1 = 135     sp_cy  = cage_yc
ear_cx   = 51.4    ear_cz = 182.9
ear_pl_y1 / ear_pl_y0 / ear_duct_y / ear_duct_y2 and every ear_ducts coordinate:
  scale by 1.25 as well
```

Verify with the existing empty-render checks: `panda_head_cavity()` minus the skin
must render empty, and all three ducts per ear must terminate inside the cavity.

## 6. Everything else that moves

* `cover_screws` - the flange grows with `cage_d`; put the six back on the ledge
  (sides `x +-33`, front `y -41`, back `y +40`), all inboard of the magnet ears.
* `mag_pos` - re-verify with `refit.py` section 8 once `cage_yc` is 1. The four
  positions scale with the flange, and the hatch is now 77 x 90.
* `usb_slot_z` - keep it aligned with the ESP32's receptacle mouth
  (`esp_cz - esp_w/2 - esp_usb_out`), as fixed previously.
* `cav_clip_z`, `skin_cy`, and the `skin_inset()` erosion radius (currently a
  hard-coded 34) all need the 200 mm figures: `skin_cy` ~-5, radius ~62.

## 7. Order of work

1. `dimensions.scad` - sections 1, 2, 3, 4 above.
2. `panda.scad` - `panda_raw()` transform, then section 5, then the rump joystick
   cuts (bore + PCB pocket + wider insertion channel) and the USB cut.
3. `cage.scad` - joystick to the outer face (section 4), then re-check the ESP32 /
   RTC / DFPlayer / speaker / cover positions against the taller, deeper box.
4. `python verify_cage.py stl/cage.stl` and the `breach` fit-check mode.
5. `./render_previews.sh` and re-export all STLs.
6. Update `README.md` (drop the "swap is pending" section), `docs/ASSEMBLY.md`
   (joystick fitting order changes), `docs/MEASUREMENTS.md` (cage envelope).

All six steps are done. `verify_cage.py` passes, `verify_window.py` passes, and the
breach check - a 0.27 mm speck on the old host - now renders completely empty.

---

## 8. Corrections found while applying it

The spec above is accurate about the cage envelope, `shell_prof`, the OLED, the
joystick and the head. Six things it got wrong or left out, all caught by measuring:

1. **`front_rim` cannot stay positive** (section 6 does not mention the flange's
   front). Over the flange's own Z band (panda Z7..11.2) the belly bottoms out at
   Y44.38 around \|X\|27, so a 4 mm outward front rim - panda Y49 - pokes out of the
   belly across \|X\|15..27. It is now `front_pull = 3` (panda Y42). The BACK, by
   contrast, gained an outward rim: the rump gives 10 mm+ there at cage_d 88.

2. **The magnet positions do not simply "scale with the flange".** `(+-34, -40)`
   scaled to panda Y50 fails: at panda Z7 the foot's inner edge is at \|X\|~28 and
   the skin there is only Y52.4, so the pocket's outboard halo breaks out. Solved
   positions are cage `(+-38, -49)` and `(+-44, -16)`. Note also that refit.py's
   original `solid_at()` was a convex `back < y < front` test, which calls the gap
   between the feet and the belly solid - it is now a crossing-parity test.

3. **The front cover screws cannot go at `y -41`.** `shell_prof` row 0 sets the
   front face back 2.22 mm, so the front ledge's outer edge walks from y-39.78 at
   cage Z0 to y-42 at Z4. `-38.5` is the only band on the ledge over the whole
   0..6 run. (Sides `+-33` and back `+40` are as specified.)

4. **The base cover cannot be a flat plate at `cage_z0` 7.** The sculpt's base is
   domed - at panda Z2 its silhouette has tucked back to Y40.3 at X0 and Y28.7 at
   \|X\|34 - so a 7 mm prism of the cage footprint stands up to 14 mm proud of the
   belly. It is now intersected with the sculpt. The base hatch was likewise
   changed from a plain `cage_d + 2` rectangle to the cage's own row-0 section, so
   it stops cutting 3 mm further forward than the cage actually reaches.

5. **The ear's Y values must be re-measured, not scaled by 1.25** (section 5 says
   to scale them). `ear_cx` and `ear_cz` do scale - 51.4 / 182.9 is right, and the
   density centroid confirms 51.46 / 183.35 - but `panda_y_off` moved from a
   hand-fitted 26 to a derived 9.036, so the whole Y frame shifted. The old plenum
   at Y13.5..18.0 scaled to 16.9..22.5 is ~20 mm outside this mesh; measured, it is
   Y-7.8..-2.2. The duct START points must also keep their original (unscaled)
   offsets from the dish centre, because the grille itself does not scale - scaling
   them walks the lowest duct off the edge of the plenum it opens into.

6. **`cav_clip_z` had to go UP, not just scale.** 50 x 1.25 = 62.5, but the front
   plate now runs at panda Y45 with as little as 1.9 mm of belly over it at Z69,
   and the skin erosion is 1.35 mm - clipping there would shave the wall the OLED's
   bosses stand on. It is 71 (cage Z64), exactly where `fyb` starts. The erosion
   radius was measured at 57-60 over the pinch, so `skin_r` is 60 rather than 62,
   and `cav_*` / `skin_*` moved to `dimensions.scad` because `use <panda.scad>`
   imports modules but not variables - `cage_clip_z` was silently undef otherwise.

Also worth recording: **the OLED window no longer cuts the paws at all.** At 160 mm
it took 8.1 mm off each; at 200 mm their inboard edges are at \|X\|29.5 (panda Z40)
and \|X\|35.5 (Z47.8) against the window's 27.7. `verify_window.py` reports 0.00 mm
into the paws, 0.00 into the shoulder, 0.83 into the feet, 8188/8192 pixels visible.

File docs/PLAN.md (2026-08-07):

# Vocetempo - Development Plan

A standalone talking bedside clock built on an ESP32. Works fully offline: no
Wi-Fi, Bluetooth, internet, or phone required.

## Philosophy

1. Simplicity
2. Reliability
3. Easy maintenance
4. Easy future expansion

Build a working breadboard prototype first. Only design a PCB/enclosure once
all features work.

## Hardware

| Part | Component | Interface | Notes |
| --- | --- | --- | --- |
| MCU | DollaTek ESP32 (ESP-WROOM-32, CP2102)  | USB-C | Main controller |
| Display | Hailege 2.42" SSD1309 128x64 | I2C | Clock, menus, icons |
| RTC | DollaTek DS3231 + AT24C32 | I2C | Accurate timekeeping; no battery yet |
| Audio | DFPlayer Mini | UART | Plays speech clips from its own microSD|
| Speaker | CQRobot 3W 4ohm | analog | Wired directly to DFPlayer |
| Storage | microSDHC 32GB (FAT32) | - | Used only by DFPlayer |
| Input | KY-023 analog joystick | ADC+GPIO  | Deadzone, hysteresis, debounced |
| Power | 5V USB wall charger | USB-C | Wall powered; no battery in v1 |

### Communication architecture

- OLED + DS3231 share the I2C bus.
- DFPlayer connects over UART.
- Speaker connects directly to the DFPlayer.
- Joystick: two axes on ADC1 (GPIO 32/33), press-switch on GPIO 25.

## Version 1 feature list

- Clock display: HH:MM (seconds optional later), date, weekday.
- Manual announcement: press a button, clock speaks the current time.
- Automatic announcements: Off / Hourly / Every 30 min / Every 15 min.
- Quiet hours: configurable start/end; auto announcements disabled, manual still works.
- Settings stored in ESP32 flash (Preferences/NVS): interval, quiet hours,
  volume, brightness, time, date, optional 12/24h mode, DST region.
- Automatic DST for a selectable region (off by default). Computed on-device
  from algorithmic rules, so it needs no network and no timezone database; see
  `include/Dst.h`. The RTC holds standard time and the offset is applied on
  read, so the hardware clock is never rewritten for a transition.
- Display brightness (future): day/night with automatic switching.

## Audio design

Use modular audio clips ("It is", "Fourteen", "Thirty", "PM"), played in
sequence. Avoids one MP3 per time and makes multi-language support easy later.

## Suggested libraries

- Display: Adafruit_GFX + Adafruit_SSD1306 (SSD1309 compatible)
- RTC: RTClib
- Audio: DFRobotDFPlayerMini
- Buttons: Bounce2 (debouncing)
- Settings: ESP32 Preferences

## Development stages

1. Verify ESP32 programming. Display "Hello". **<- current**
2. Connect OLED. Display text.
3. Connect RTC. Read + display time.
4. Set RTC manually. Verify persistence while powered.
5. Connect DFPlayer. Play one test audio.
6. Connect speaker. Verify volume.
7. Read buttons.
8. Manual speech: press button, speak time.
9. Automatic announcements.
10. Quiet hours.
11. Settings menu + storage.
12. Long runtime testing (stability, RTC accuracy, timing).

For each stage: explain wiring, explain the code, verify behaviour, then continue.

## Host unit tests

The hardware-free logic is unit-tested on the development machine with
`pio test -e native` (Unity, `test/`). Currently covered:

- `Dst` - daylight-saving rules and calendar maths, checked either side of every
  transition instant across several years and both hemispheres.
- `Announcer` - interval boundaries, quiet-hours windows, and the behaviour
  across DST transitions (a repeated hour must not silence the clock).
- `Joystick` - deadzone, hysteresis against ADC noise, and the dominant-axis
  latch that stops a diagonal push firing two actions at once.

This is the cheapest place to catch timing bugs, since neither class touches
I2C, UART or NVS. Prefer adding logic here over testing it only on hardware.

## Future (v2)

Battery operation, 18650 + USB charging, supercapacitor RTC backup, automatic
brightness, custom PCB, 3D-printed enclosure, larger speaker, multilingual
speech, voice selection, alarm, more DST regions.

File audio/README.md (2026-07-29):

# Vocetempo - Audio clips

Speech clips for the DFPlayer Mini. Files live in `mp3/` named `0001.mp3`,
`0002.mp3`, ... and are addressed by index from the firmware
(`audio.playIndex(n)` -> `/mp3/000n.mp3`).

## microSD layout

Copy the `mp3/` folder to the root of a FAT32-formatted card, then strip
macOS metadata before using it in the DFPlayer:

```sh
cp -R mp3 "/Volumes/<CARD>/mp3"
dot_clean "/Volumes/<CARD>"
# remove Spotlight/fseventsd dirs and disable indexing:
rm -rf "/Volumes/<CARD>/.Spotlight-V100" "/Volumes/<CARD>/.fseventsd"
mdutil -i off "/Volumes/<CARD>"
diskutil eject "/Volumes/<CARD>"
```

## Generating clips (macOS)

Clips are synthesized with the built-in `say` TTS and boosted for loudness so
they are clearly audible through the small speaker at DFPlayer volume 30.

Example (the current `0001.mp3`, "It is"):

```sh
say -v Samantha -o tmp.aiff "It is"
ffmpeg -y -i tmp.aiff \
  -af "acompressor=threshold=-20dB:ratio=6:attack=3:release=80:makeup=8,volume=6dB,alimiter=level_in=1:level_out=1:limit=0.97" \
  -ar 44100 -ac 1 -b:a 128k mp3/0001.mp3
rm tmp.aiff
```

The compressor + gain + limiter chain raises the average level (mean volume
about -9.5 dB, peaks at 0 dB) without hard clipping. Check levels with:

```sh
ffmpeg -i mp3/0001.mp3 -af volumedetect -f null /dev/null 2>&1 | grep volume
```

## Clip set (full pre-rendered phrases)

The clock speaks each time as ONE complete pre-rendered sentence, so playback
is gapless and naturally intonated (the DFPlayer is slow at chaining files,
which made the earlier word-by-word approach sound choppy).

Index scheme (files mp3/NNNN.mp3), 12-hour format:

    index = hour24 * 60 + minute + 1      (range 1..1440)

Examples:
    00:00 -> 0001.mp3  "It is midnight"
    12:00 -> 0721.mp3  "It is noon"
    09:05 -> 0546.mp3  "It is nine oh five A.M."
    22:45 -> 1366.mp3  "It is ten forty-five P.M."

The firmware's speakTime() (src/Audio.cpp) computes this index and plays the
single file. The formula there MUST match generate_phrases.py.

Regenerate all 1440 English phrases:

```sh
cd audio
python3 generate_phrases.py --voice Samantha --workers 8
```

## Multi-language (English / Portuguese-PT / Spanish)

This DFPlayer clone only supports playMp3Folder(n) -> /mp3/NNNN.mp3 (folder
addressing via playFolder/playLargeFolder does NOT work on it, verified on
hardware). So all languages live in /mp3 using a per-language INDEX OFFSET:

| Language | Voice | Index range | Offset |
| --- | --- | --- | --- |
| English | Samantha | 0001..1440  | 0 |
| Portuguese (PT) | Joana | 2001..3440  | 2000 |
| Spanish (MX) | Paulina  | 4001..5440  | 4000 |

For a given language: `index = offset + hour24 * 60 + minute + 1`.
The firmware's languageOffset() (Settings.h) and Audio::speakTime() implement
this; the menu's Language item selects it and it persists in NVS.

Regenerate Portuguese + Spanish (English via generate_phrases.py above):

```sh
cd audio
python3 generate_multilang.py --langs pt es --workers 8
# add --skip-existing to resume an interrupted run
```

Grammar handled per language (e.g. PT "E uma" vs "Sao duas"; ES "Es la una"
vs "Son las dos"), with accented text for correct pronunciation.

(generate_clips.py is the older modular word-clip generator, kept for
reference but no longer used.)

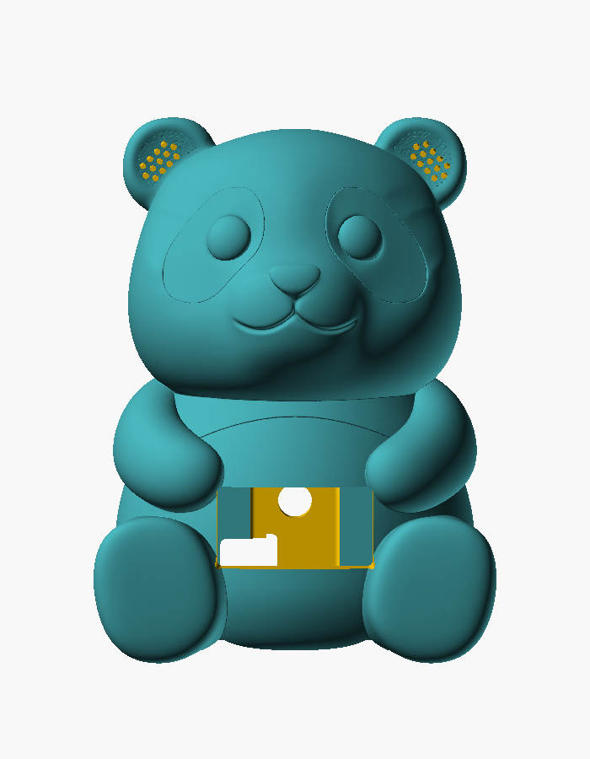
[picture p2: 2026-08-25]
enclosure/previews/panda_cut_front.png

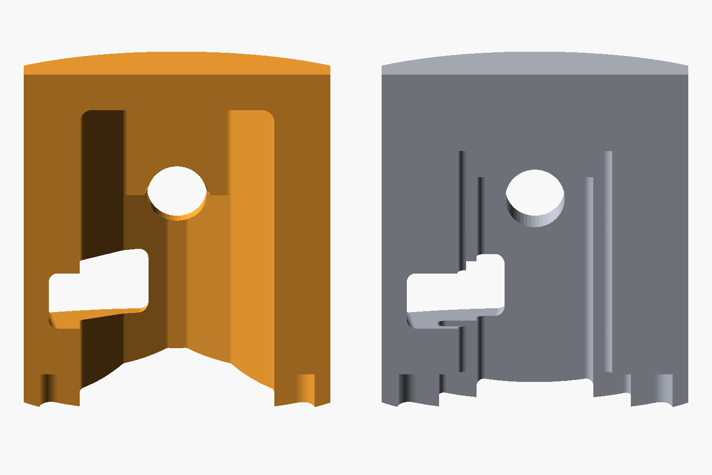
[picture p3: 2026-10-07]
enclosure/previews/joystick_channel_comparison.png

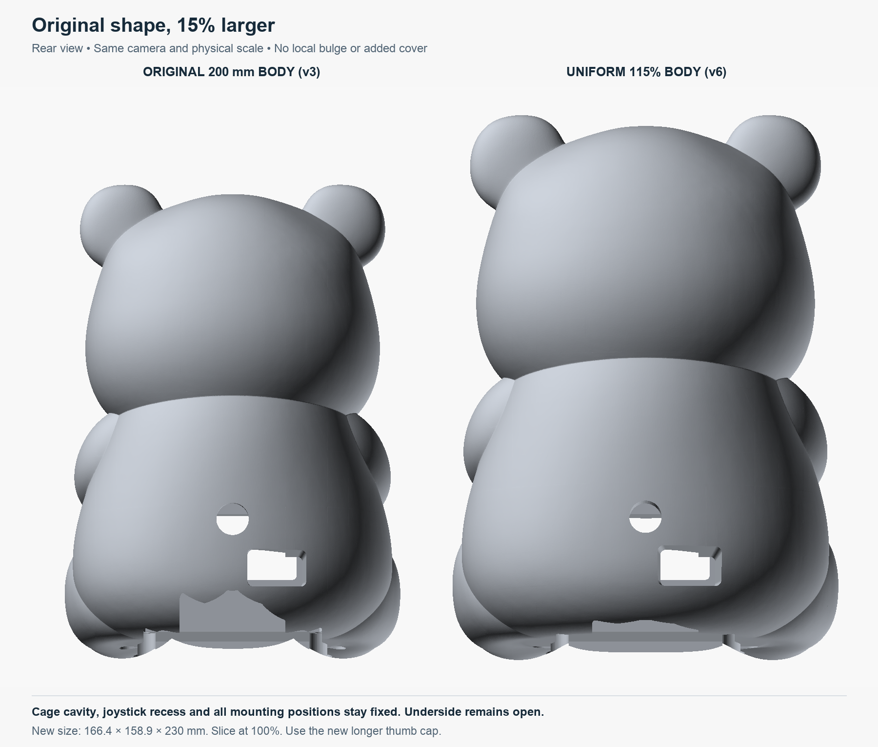
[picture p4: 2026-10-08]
enclosure/previews/uniform_body_comparison_v6.png

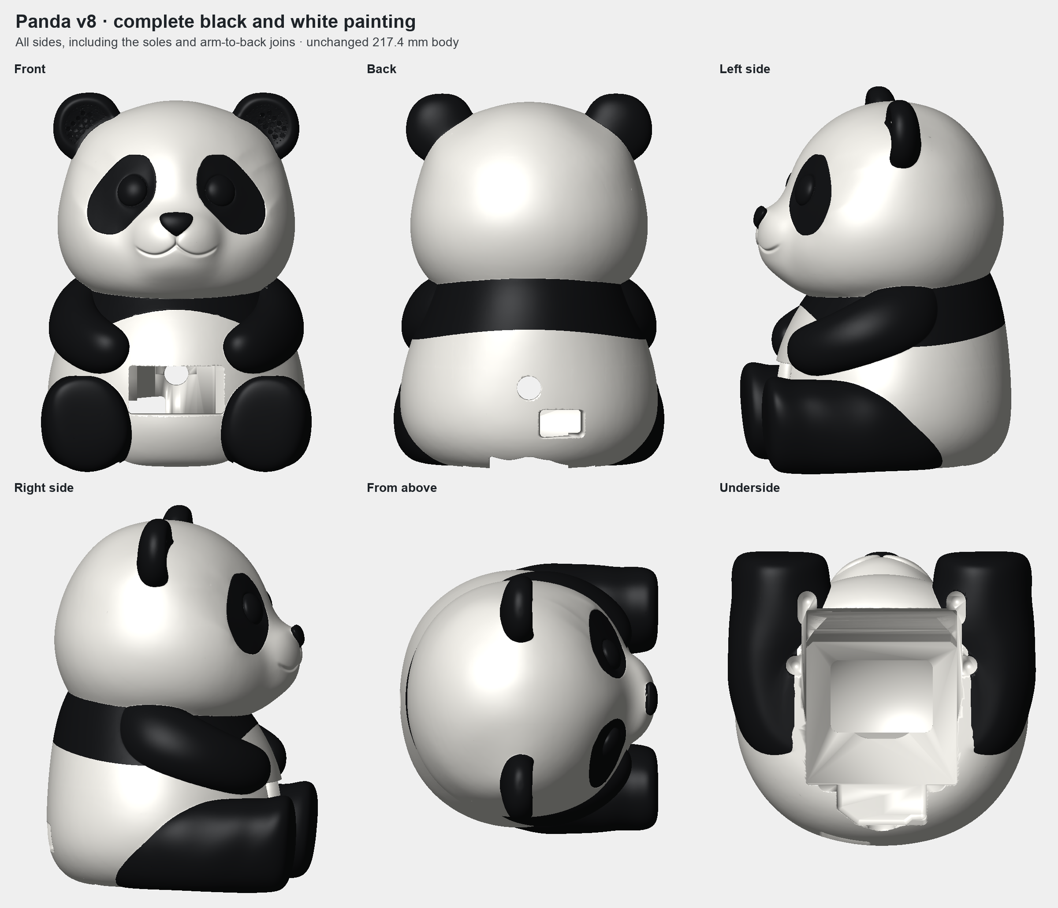
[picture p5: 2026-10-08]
enclosure/previews/panda_body_v8_paint_full_views.png

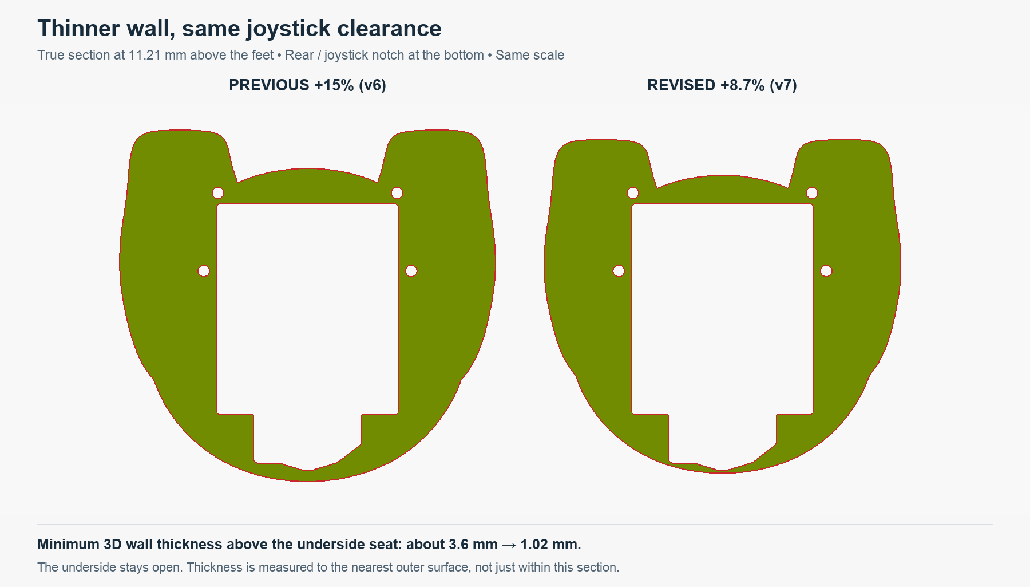
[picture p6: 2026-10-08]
enclosure/previews/uniform_body_section_v7.png

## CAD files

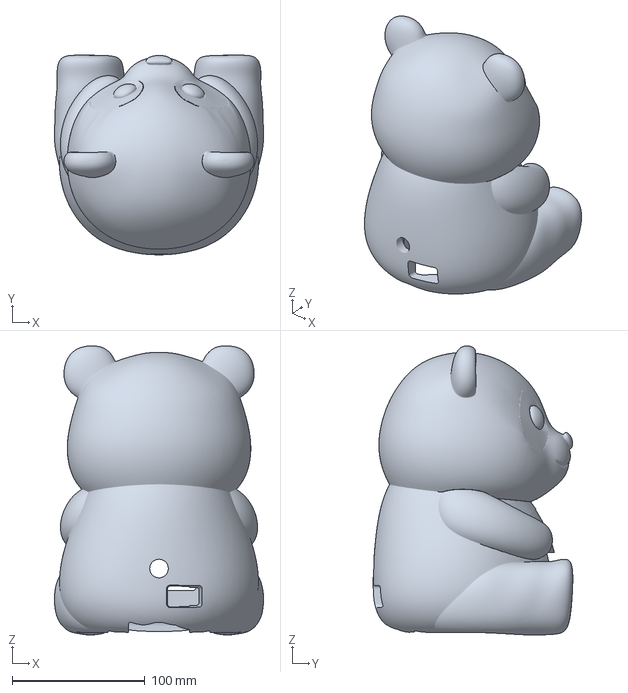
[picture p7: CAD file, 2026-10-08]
enclosure/3mf/panda_body_uniform_v8_black_white_full.3mf
157.3 x 150.2 x 217.4 mm

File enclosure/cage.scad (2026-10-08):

// ============================================================================
// Vocetempo - electronics CAGE.
//
// The real mechanical deliverable: a printable box that holds every module and
// slides into the hollowed panda FROM BELOW (base hatch). The panda mesh is
// hollowed and openings are cut to match this cage - the cage is designed
// first, the body adapts to it.
//
// Coordinate convention (matches dimensions.scad):
//   +X right,  +Y = toward the BACK wall (front face is at -Y, faces the belly),
//   +Z up.  Cage base rim sits on the local Z=0 plane here; in the panda it is
//   lifted to cage_z0.
//
// FRONT FACE  (-Y): the OLED, and nothing else - it is 68.63 x 46.60 and there was
//                   never room for a second device here.
// BACK WALL   (+Y): the JOYSTICK, bolted to standoffs on the wall's OUTER face so
//                   the gimbal points away from it into the rump, plus the DFPlayer
//                   and the USB-C charge exit inside, below it.
// SIDE WALLS  (+-X): ESP32 (left, portrait), RTC + DFPlayer (right). Moved off the
//                   back wall to make room for the joystick - and they are better
//                   off here anyway, because the shell's corner chamfers barely
//                   touch the side faces (at the worst height the side wall is
//                   still 38.7mm deep).
// TOP FACE    (+Z): speaker, grille up, firing into the head cavity.
// BASE        (-Z): the hatch the cage enters through - open for assembly, then
//                   closed by the printed BASE COVER (part = "cover").
//
// Everything dimensional comes from dimensions.scad. Nothing is hard-coded that
// has a variable there.
// ============================================================================

include <dimensions.scad>
include <helpers.scad>
use <panda.scad>          // for skin_inset(): trims the cage's upper front-side corners
                          // to the SAME inward-eroded skin the body cavity is clipped to,
                          // so the cage matches the thickened belly wall at the arm-fold
                          // and still seats. (Only the feature-free corners are shaved -
                          // clear of the OLED standoffs.) Loads the panda mesh on render.

// ---- Local shorthands ------------------------------------------------------
W  = cage_w;        // 75  outer width  (X)
H  = cage_h;        // 80  outer height (Z)
D  = cage_d;        // 88  outer depth  (Y)
t  = sled_wall;     // 2.0 cage wall thickness
eps = 0.01;         // tiny overlap so booleans cut cleanly

// Inner cavity (the usable volume once walls are removed).
IW = W - 2*t;
ID = D - 2*t;
IH = H - t;         // base is OPEN, so only the top eats a wall

// Front face is the plane y = -D/2 (outer) / y = -D/2 + t (inner).
// Back  wall is the plane y = +D/2.

// ---------------------------------------------------------------------------
// SHELL: a box open on the bottom (base hatch). It is built from shell_prof
// (dimensions.scad) via shell_stack (helpers.scad): a W x D rectangular cross
// section that is FLAT and FULL through the whole board-mounting zone, and only
// chamfered at the corners near the feet (low) and the shoulders/arms (high).
// This is what keeps every mounting boss backed by a real, flat wall (a plain
// box poked its corners through the round panda; a naive taper moved the walls
// away from the bosses so they floated - both are fixed here).
//
// shell_solid(shrink, ztop): the FILLED shell body (cavity not removed), inset by
// `shrink` and clipped to height `ztop`. shrink=0 is the outer surface; shrink=t
// is the inner surface used to carve the wall. It doubles as the "is this inside
// the shell?" oracle used to clip the bosses (see cage()).
module shell_solid(shrink = 0, ztop = H) {
    intersection() {
        shell_stack(shell_prof, shrink);
        translate([-200, -200, -50]) cube([400, 400, 50 + ztop]);
    }
}

module cage_shell() {
    difference() {
        shell_solid(0, H);                       // outer
        // interior: same shape inset by the wall thickness, dropped below the base
        // (open hatch) and capped t below the top (leaves the top wall).
        translate([0, 0, -2*eps]) shell_solid(t, H - t);
    }
}

// ---------------------------------------------------------------------------
// BASE RIM + MAGNET POCKETS.
// A shallow outward flange around the open base gives the cage a face to seat
// against the body's hatch collar and houses the 4 retention magnets. Pockets
// are OPEN (through the flange) so the magnet face sits flush and meets its
// body-side partner metal-to-metal. Pocket depth = magnet_t (flush).
// ---------------------------------------------------------------------------
// The footprint (core rim + the four magnet ears) lives in helpers.scad as
// base_flange_2d(), shared with the panda's rebate so the two cannot drift.
// rim_h / flange_xw / front_yf / back_yb / mag_pos are in dimensions.scad.
flange_lead = 1.5;      // step-back on the flange's bottom edge (see below)
module base_flange() {
    difference() {
        // The bottom flange_lead of the rim is stepped back. Two reasons: it is a
        // lead-in that helps the flange find its rebate, and it clears a small
        // breach - the flange's FRONT rim at panda Y44 was up to 0.47mm proud of
        // the sculpt's base fillet over panda Z2.00..2.47, |X|<26 (found by the
        // fitcheck "breach" mode). A step rather than a chamfer because
        // base_flange_2d() is non-convex (the magnet ears), so hulling two offsets
        // of it would bridge straight across between the ears.
        union() {
            linear_extrude(flange_lead)
                offset(delta = -flange_lead) base_flange_2d();
            translate([0, 0, flange_lead])
                linear_extrude(rim_h - flange_lead) base_flange_2d();
        }
        // keep the interior open (don't block the hatch).
        // BUG FIX 2026-08-20: this used to be
        //     translate([0,0,-eps]) cube([IW, ID, rim_h + 2*eps], center = true)
        // and `center = true` centres in Z as well, so the cube only reached
        // z = rim_h/2 (2.09) - leaving the top HALF of the flange solid right
        // across the base. The cage as printed therefore has a 2.1mm floor over
        // its whole footprint at Z2.1..4.2: measured on the exported STL, a
        // Z-ray anywhere in the base returns [2.1, 4.2]. That is not the open
        // hatch the design describes, and it sits directly under the DFPlayer's
        // SD slot and the ESP32's USB-C, both of which face down at it.
        translate([0, 0, -eps])
            linear_extrude(rim_h + 2*eps)
                square([IW, ID], center = true);
    }
}

// 4 magnet pockets, flush with the flange's TOP face (+Z) - that face is where the
// pair meets its body-side partner, which is recessed into the rebate's ceiling. The
// pocket bottoms out on 1.2mm of backing (rim_h - magnet_t) so the magnet cannot be
// pushed straight through, and is undersized by magnet_fit per side for a press fit.
// CHECK POLARITY against the body magnet before gluing (see dimensions.scad).
module magnet_pockets() {
    for (p = mag_pos)
        translate([p[0], p[1], rim_h - magnet_t])
            cylinder(h = magnet_t + eps, d = magnet_d - 2*magnet_fit);
}

// ---------------------------------------------------------------------------
// FRONT-FACE LAYOUT (the -Y wall): the OLED, alone.
// Z runs 0 (base) .. H (top). oled_cz comes from dimensions.scad (single source of
// truth), derived from dev_oled_pz and cage_z0 so cage Z + cage_z0 = panda Z.
// With dev_oled_pz = 47.8 the PCB spans cage Z14.4..61.0 and all four mounting
// bosses (at Z16.2 and Z59.2, |X|32.15) land on FLAT wall: shell_prof's cf is 0
// through cage Z42 and never exceeds 1.92, so a chamfer cannot reach them.
// ---------------------------------------------------------------------------
front_y      = -D/2;                 // outer plane of the front wall

// ---------------------------------------------------------------------------
// OLED: window through the front wall (at the LIT area, offset +3.1 up), plus
// four standoffs behind the wall on the measured 64.3 x 43.0 / Ø2.5 pattern.
// The window is positioned by the OLED's active-area centre, which sits at
// (oled_active_dx, oled_active_dy) relative to the PCB centre (oled_cz).
// ---------------------------------------------------------------------------
module oled_window_cut() {
    // active-area centre in cage coords
    ax = oled_active_dx;
    az = oled_cz + oled_active_dy;
    translate([ax, front_y + t/2, az])
        rotate([90, 0, 0])
            linear_extrude(height = t + 4, center = true)
                offset(r = 1.5)   // rounded corners + a little bezel clearance
                    square([oled_active_w + fit_gap, oled_active_h + fit_gap],
                           center = true);
}
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

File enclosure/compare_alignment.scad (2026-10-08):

// Visual comparison only. Uses frozen print exports; does not change any part.
// Original body = v3, before outer scaling, including the approved entrance fix.
// Current body = v8, 108.7% outer sculpt and corrected speaker inlet.
// Both use the EXACT same already-printed cage at its existing placement.
// Render with --backend=Manifold --render --imgsize=1800,850
// --projection=orthogonal --colorscheme=Tomorrow.
// Camera: --camera=0,0,53,90,0,0,520 for section;
//         --camera=0,0,49,90,0,0,520 for front/rear.
// Keep both models in one render: do not fit each model to its own frame.
include <dimensions.scad>
view = "section"; // section, front, rear
before = "stl/panda_body_entrance_relief_v3.stl";
after = "stl/panda_body_uniform_v8.stl";
body_color = [0.78,0.79,0.81];
cage_color = [0.08,0.43,0.65];

module body_mesh(file) { import(file, convexity=12); }
module printed_cage() {
    translate([0,cage_yc,cage_z0]) rotate([0,0,180])
        import("stl/cage.stl", convexity=12);
}
module centre_section() {
    intersection() {
        children();
        translate([-0.15,-150,-1]) cube([0.3,300,121]);
    }
}
module assembly_section(file) {
    rotate([0,0,90]) {
        color(body_color) centre_section() body_mesh(file);
        color(cage_color) centre_section() printed_cage();
    }
}
module exterior(file, back=false) {
    rotate([0,0,back ? 0 : 180]) {
        intersection() {
            color(body_color) body_mesh(file);
            translate([-150,-150,-1]) cube([300,300,106]);
        }
        color(cage_color) printed_cage();
    }
}
if (view == "section") {
    translate([-86,0,0]) assembly_section(before);
    translate([86,0,0]) assembly_section(after);
}
else if (view == "front" || view == "rear") {
    translate([-86,0,0]) exterior(before, view == "rear");
    translate([86,0,0]) exterior(after, view == "rear");
}

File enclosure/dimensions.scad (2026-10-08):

// ============================================================================
// Vocetempo enclosure - shared component dimensions.
//
// These are the real-world sizes of every part that has to fit in (or show
// through) the enclosure. EVERY concept file includes this one, so we only
// ever edit measurements in a single place.
//
// !!! IMPORTANT !!!
// The values below are NOMINAL (typical datasheet / "as sold" numbers). Before
// exporting a FINAL printable case, measure YOUR actual boards with calipers
// and update them here - clones vary by a couple of mm, which is the
// difference between a snug case and one that doesn't close. For picking a
// concept shape, nominal values are fine.
//
// docs/MEASUREMENTS.md is a fill-in checklist covering every value marked
// [verify] below, including how to measure the awkward ones (hole centres, the
// OLED's lit area, the joystick's tilt angle).
//
// Units: millimetres. Coordinate convention used by the concepts:
//   +X right, +Y up (away from viewer / toward the panda's back is -Y),
//   +Z up (vertical). The panda sits on the Z=0 ground plane.
// ============================================================================

// ---- OLED: Hailege 2.42" SSD1309, I2C -------------------------------------
// MEASURED 2026-08-04. The old nominals were well off: the real board is 3.4mm
// narrower and 6.6mm TALLER than assumed (72x40 -> 68.63x46.60), which would
// have made any case built on the old numbers unusable.
oled_pcb_w      = 68.63;  // PCB width  (X)  [measured]
oled_pcb_h      = 46.60;  // PCB height (Y)  [measured]
oled_pcb_t      = 0.98;   // PCB thickness   [measured] (thin 1.0mm board)
oled_glass_w    = 62.30;  // glass panel width  [measured]
oled_glass_h    = 39.90;  // glass panel height [measured] at its widest; there
                          // is a ~1mm slope/notch at the bottom middle
// Active area derived from the 2.42" diagonal at the panel's 2:1 aspect
// (128x64 square pixels): 61.47mm diagonal -> 54.98 x 27.49.
// The previous oled_active_h of 37.0 was geometrically impossible.
// Confirm both against the lit rectangle with `pio run -e oled_test`.
// Confirmed with oled_test (all pixels on) against the lit rectangle. Height 28
// finally buries the old impossible 37.0. Edge-to-lit gaps: L=R=7.35 (centred
// in X); top=6.2, bottom=12.6 -> lit sits 3.1mm ABOVE the PCB centre (toward the
// top edge, away from the bottom pin header). The window must NOT be centred.
oled_active_w   = 55.0;   // lit area width  [measured]
oled_active_h   = 28.0;   // lit area height [measured]
oled_active_dx  = 0;      // X offset from PCB centre (horizontally centred) [measured]
oled_active_dy  = 3.1;    // Y offset from PCB centre, +Y toward top edge [measured]
// Mounting holes: 4, one at each corner of a plain rectangular PCB, ~1mm from
// the edges. Spacing derived from edge->hole readings cross-checked against the
// board size; both reconcile with a sane wall thickness (0.9mm H, 0.55mm V).
oled_hole_dx    = 64.3;   // hole horizontal centre-to-centre [measured]
oled_hole_dy    = 43.0;   // hole vertical   centre-to-centre [measured]
oled_hole_d     = 2.5;    // mounting-hole diameter (M2 clearance) [measured]

// Depth behind the glass front face, which sets how deep the panel recess must
// be. The header adds 6.3mm; cutting it down or fitting a right-angle one would
// save that much sled depth.
oled_depth_bare = 6.23;   // glass front -> back of PCB          [measured]
oled_depth_hdr  = 12.55;  // glass front -> back of soldered header [measured]

// ---- THE BELLY WINDOW: the full lit area, and what it costs ----------------
// DECISION (user): every one of the 128x64 pixels must be visible. So the window
// is the whole lit area + fit_gap, 55.4 x 28.4, and the folded paws that stand in
// front of it are simply CUT THROUGH. That is a deliberate trade, not an oversight
// - the alternatives were measured and all cost more (see below).
//
// WHAT GETS CUT. The paws' inboard edges reach X-19.6 at Z51 while the window needs
// 27.7, so the cut takes 8.1mm off each paw, over Z42..58, leaving a flat vertical
// face on the inboard side of each. The arms therefore end abruptly at the screen
// rather than reading as folded. Nothing else on the body is touched.
//
// THE CORNER RADIUS is the one real knob, and it does NOT affect the paw cut at all
// (8.10mm at Z50.5 for every radius, because that height is in the window's
// full-width span). It only trades CORNER PIXELS against the FEET, whose inner
// edges come to |X| 24.7 at Z32. Measured:
//     r      lit px hidden   corner icons   bite into the feet
//     2.0        4 / 8192    both survive   2.1mm at Z32..35
//     4.0       48           both clipped   1.1mm
//     6.0      120           both clipped   0.04mm
//     8.0      236           both clipped   none        <- what this used to be
// r = 2.0 is chosen because the requirement is all pixels visible: it hides 4 of
// 8192 (the single extreme pixel in each corner) and keeps the quiet-hours and mute
// icons, which sit in the top corners, on screen. The price is a ~2mm nick out of
// each foot's top-inner corner - next to an 8.1mm paw cut, it does not show.
//
// WHAT WAS REJECTED, all built and measured:
//  * Sizing the window to the sculpt's own embossed screen plaque (36 x 21mm, its
//    raised frame becoming the bezel). Geometrically perfect - nothing trimmed or
//    deformed, rim on flat plaque to +-0.15mm - but it only exposes an 84 x 48
//    safe area of the panel, so a third of the pixels are hidden. Rejected.
//  * Countersinking the window (oled_bevel_*): left two flat "wings" beside the
//    screen ending in a hard crescent line.
//  * A rolling-ball paw trim (arm_trim()): rolled the sculpted paw tip into a
//    spherical dome and planed its crest.
//  * Swinging the arms outboard in Blender first (panda_arms.py). This DID free the
//    paws and keep them fully rounded, and it cleared this exact window with a
//    1.3..2.1mm bezel. But there are only 2.6mm of surface between the paw's
//    underside (Z42) and the top of the feet (Z39.4), so the swing's taper either
//    tore a serrated ridge across the belly or sheared the leg tops into POINTY
//    TIPS; the best of ~30 swept configurations still rotated the legs 13mm and
//    visibly widened the stance, and left only 1.3mm of bezel on the -X side (the
//    sculpt's paws are not symmetric). A biharmonic solve was 20x worse still,
//    because the sculpt's triangulation is far too irregular for a Laplacian
//    method. Rejected as costing more than the paw cut it was avoiding.
//  * A smaller 1.54" 128x64 panel (~35 x 17.5mm active) would fit the plaque
//    entirely - all pixels, panda untouched, no firmware change - but needs a
//    different module, a new cage OLED mount, and gives a much smaller clock.
//    Worth revisiting if the sliced paws ever grate.
oled_win_w      = 55.4;   // = oled_active_w + fit_gap; full lit width
oled_win_h      = 28.4;   // = oled_active_h + fit_gap; full lit height
oled_win_r      = 2.0;    // corner radius; see the table above before changing

// ---- ESP32 DevKit (DollaTek 30-pin) ---------------------------------------
esp_w           = 53.20;  // board length (X) [measured]
esp_h           = 28.40;  // board width  (Y) [measured]
esp_t           = 1.45;   // PCB thickness (ignoring pin headers below) [measured]
esp_top_h       = 4.63;   // tallest point above the top face (chip/can; USB-C
                          // shell is the same height) - sets sled clearance [measured]
esp_usb_w       = 8.80;   // USB-C receptacle shell width [measured]
esp_usb_h       = 3.10;   // USB-C port opening height for the wall cutout [measured]
esp_usb_out     = 1.5;    // how far the receptacle sticks out past the PCB edge [measured]
// CHARGING ROUTING (decided): ESP32 mounts USB-C-DOWN; the cable curves ~90deg
// in the board-to-wall gap and exits a SLOT LOW ON THE BACK WALL (not the base,
// which faces the table). The slot is sized to a PANEL-MOUNT USB-C flange so a
// fixed back port can be retrofitted later without a redesign; for now a loose
// cable threads it. See usb_exit_cut in cage.scad.
esp_pin_drop    = 10;     // clearance needed below the board for header pins
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

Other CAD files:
enclosure/3mf/panda_body_uniform_v8_black_white.3mf
enclosure/3mf/panda_colored_final.3mf
enclosure/3mf/panda_body_uniform_v8_black_white_precision.3mf
enclosure/3mf/panda_body_uniform_v8_black_white_detailed.3mf
enclosure/fitcheck.scad
enclosure/helpers.scad
enclosure/layout_walls.scad
enclosure/panda.scad

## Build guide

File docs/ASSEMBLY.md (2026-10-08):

# Vocetempo - Assembly, Soldering & Enclosure Plan

How to take the working breadboard build and make it permanent, serviceable and
reliable. Wiring itself (which pin goes where) is in [`WIRING.md`](WIRING.md);
this document is about the physical build.

---

## 1. The sled concept - review

The plan is a rectangular opening in the body, and a separate box ("the sled")
carrying all the electronics that slides in and out, held by magnets and
screws, with the speaker poking up through the sled's roof into the head.

**This is the right architecture, for one reason above all: no wire crosses the
boundary.** Every failure I would expect in a design like this comes from
cabling that has to be unplugged to open the case, or that flexes every time you
do. If the speaker rides on the sled and fires *up into* the head - rather than
being mounted in the head and wired down - then the sled is a single
self-contained unit with exactly one thing attached to the outside world: the USB
lead. That is as good as it gets.

Three changes worth making:

**a) The sled's front face should be the visible front panel.** Put the OLED and
the joystick on it. If they are mounted in the body instead, their wires cross
the boundary and the whole benefit is lost. The belly opening becomes a flat
recessed rectangle that the sled face fills.

**b) Magnets *or* screws for routine access, not both.** Two magnets and two
screws means undoing screws every time, so the magnets are decoration. Use
magnets as the only routine retention, and add the screws as an *optional*
lock - handy if the clock ever travels, unnecessary on a bedside table. If you
do want both, put the screws where a screwdriver reaches without moving the
clock (i.e. the underside, not the back).

**c) Seal the speaker to the sled roof.** A speaker with an open back cancels
its own bass - the rear wave meets the front wave and the low end largely
disappears. Mounting it in the sled roof does something genuinely good here: the
head becomes the front chamber and the sled interior becomes the sealed rear
volume. That only works if the joint is airtight, so fit a thin foam or silicone
gasket between the speaker flange and the sled roof. It is the difference
between a tinny beep and a voice.

---

## 2. Extra parts to buy

| Part | Spec | Why |
| --- | --- | --- |
| Perfboard | ~70 x 50 mm, 2.54 mm pitch | Sled backbone (`perf_w`/`perf_h`) |
| Female header strip | 2.54 mm, ~60 pins total | Sockets so modules unplug |
| Neodymium discs | 6 x 3 mm, x2-x4 | Sled retention (`magnet_d`) |
| Steel washers | M4-M6, 12 mm OD, x2-x4 | Magnet counterpart in the body |
| Heat-set inserts | M3 brass, 4.2 mm OD | Screw threads that survive re-use |
| Screws | M3 x 8 mm cap head | Optional sled lock |
| Electrolytic cap | 470 µF, 6.3 V+ | DFPlayer bulk decoupling - see §3 |
| Ceramic caps | 2 x 100 nF | Local decoupling for RTC and OLED |
| JST-PH connector | 2-pin | Speaker, the one thing worth unpluggable |
| Foam/silicone strip | 2-3 mm, self-adhesive | Speaker gasket |
| Heat-shrink | 2 mm and 4 mm | Strain relief on every joint |
| Silicone wire | 26-28 AWG, stranded | Flexes without work-hardening |
| Coin cell | **LIR2032**, not CR2032 | RTC backup - see the warning in §3 |

Use **stranded silicone** wire, not solid core. Solid core is easier to poke
into a breadboard and is exactly wrong here: it work-hardens and cracks at the
solder joint after being flexed a few times, which is the classic
intermittent-fault-that-takes-a-week-to-find.

---

## 3. Electrical work to do before closing anything up

These are not optional polish. Each one prevents a specific failure.

### 3.1 Bulk capacitor across the DFPlayer's 5 V

**Do this one.** The DFPlayer's onboard amplifier pulls current in sharp bursts
as the voice plays. On breadboard wiring that shows up as audible popping, and
at worst it drags the 5 V rail down far enough to brown out the ESP32
mid-announcement - which then looks like a random reboot and is very hard to
diagnose.

Solder a **470 µF electrolytic** directly across the DFPlayer's `VCC` and `GND`
pins, as physically close to the module as possible. Watch polarity: the striped
side is negative.

### 3.2 DS3231 coin cell - read this before fitting a battery

The RTC has no backup cell yet (`PLAN.md`), so it forgets the time on every
power cut. Fitting one is the single biggest reliability win available.

> **The ZS-042-style DS3231 modules - which is what the DollaTek board is -
> include a charging circuit for a rechargeable LIR2032. If you fit a
> non-rechargeable CR2032, the board will try to charge it. A CR2032 being
> charged can leak or vent.**

Two safe options:

1. **Fit a LIR2032** (rechargeable, 3.6 V) and leave the board alone. Simplest.
2. **Fit a CR2032** and first disable the charger by removing the series diode
   (marked `D1`) or the charging resistor next to it. A CR2032 will then run the
   RTC for years.

Do not fit a CR2032 to an unmodified board.

### 3.3 Local decoupling

A 100 nF ceramic across `VCC`/`GND` at the OLED and again at the RTC. Cheap
insurance against I2C glitches on longer wiring - and the firmware already has
bus-recovery code (`main.cpp`) precisely because this bus has misbehaved before.
Better not to need it.

### 3.4 Keep the speaker leads away from the I2C pair

Route the two speaker wires down one side of the sled and the `SDA`/`SCL` pair
down the other. Speaker leads carry a relatively large swinging current; running
them alongside I2C for 10 cm is asking for corrupted reads.

### 3.5 Twist the I2C pair

Lightly twist `SDA` and `SCL` together with the ground return. Costs nothing,
measurably improves noise immunity.

---

## 4. Interconnect: socket the modules, solder the wiring

Do **not** solder the modules themselves down. Solder *female headers* to the
perfboard and plug the modules in.

```
   module (ESP32 / RTC / DFPlayer)
        │ male header pins (already on the module)
   ═════╪═════  female header, soldered to perfboard
        │
   ─────┴─────  perfboard: wiring soldered on the underside
```

Why: every interconnect is a proper soldered joint, so nothing works loose - but
any module that dies can be swapped in a minute without a desoldering iron. For
a static bedside device there is no vibration argument against sockets.

The two exceptions:

- **Speaker** - terminate in a 2-pin JST-PH so the sled roof can come off
  without cutting wires.
- **Joystick and OLED** - short flying leads soldered directly, since they are
  fixed to the sled's front face and never need to detach independently.

### Wiring the perfboard underside

- Bare tinned wire for the shared rails (a 3.3 V bus, a 5 V bus, a ground bus),
  run as straight lines along the board. Insulated jumpers for signals.
- Build the **ground bus first and make it generous.** Every reliability problem
  in a mixed digital/analog/audio build traces back to grounding. The joystick's
  ADC readings and the audio amp share this ground; a thin, shared, daisy-chained
  ground is how you get a noisy stick and a buzzing speaker.
- Star the grounds where you can: run the DFPlayer's ground back to the ESP32
  ground pin on its own path rather than chaining it through the RTC and OLED.

---

## 5. Soldering order - and what to test after each step

Solder one thing, verify it, then move on. The project already has a diagnostic
tool per subsystem, which is exactly what makes this practical. If step 5 breaks
something you know it was step 5.

| # | Solder | Verify with | Expected |
| --- | --- | --- | --- |
| 1 | Female headers + power/ground buses | Multimeter, **before** plugging anything in | 3.3 V and 5 V present at every socket; no continuity between rails; no rail-to-ground short |
| 2 | ESP32 socket only | `pio run -e esp32dev -t upload` | Boot banner on serial |
| 3 | I2C pair + OLED and RTC sockets, + 100 nF caps | `pio run -e i2c_scanner -t upload` | Devices at `0x3C`, `0x68`, `0x57` |
| 4 | OLED flying leads | `pio run -e oled_test -t upload` | Test pattern, no flicker |
| 5 | Joystick flying leads | `pio run -e joystick_test -t upload` | Idle `x`/`y` near 1900-2100, `dir=None`; each push reads correctly |
| 6 | DFPlayer socket, 1 k resistor on RX, 470 µF cap | `pio run -e folder_test -t upload` | Folder addressing works |
| 7 | Speaker JST + gasket | `folder_test` again | Clean audio, no pops between clips |
| 8 | RTC coin cell (see §3.2) | Full app; unplug 30 s; replug | Time survives, no "power was lost" in the log |
| 9 | Everything closed up | Full app, overnight soak | `[hb]` heartbeats every 60 s, heap flat |

**Check step 1 with a multimeter before any module is plugged in.** A reversed
rail will kill the ESP32, the RTC and the DFPlayer in one go, and it is the one
mistake that cannot be undone.

Then confirm the joystick orientation and, if needed, flip `kInvertX`/`kInvertY`
in `src/Buttons.cpp` - see the end of [`WIRING.md`](WIRING.md).

---

## 6. The sled

### Retention

**4 magnet PAIRS** (Ø5 x 3 mm), pockets in printed plastic on both halves, press
fit + a drop of CA. They live on the cage's **base flange**, which drops into a
rebate counterbored into the panda's base (`panda_base_rebate()`); the pairs meet
on the flange's **top face**, cage magnet looking up and body magnet recessed into
the rebate's ceiling looking down, so the two faces touch with nothing between
them. That matters: with a plastic wall between them a Ø5x3 pair holds ~0.4 N in
shear, touching it is ~2 N, so 4 pairs give ~8 N against a ~2 N cage.

Positions are `mag_pos` in `dimensions.scad` - a front pair out over the feet and
a side pair over the base's side collar. They **must** sit outboard of the base
hatch: the hatch removes the body exactly where an earlier version put them, so
they had nothing to attract at all.

Pockets are modelled `magnet_fit` (0.05 mm) undersize per side for a press fit,
and bottom out on 1.2 mm of backing (`rim_h - magnet_t`) so a magnet cannot be
pushed through. If a pocket prints loose, CA is fine - but push the magnet in
**before** the glue grabs, because a magnet stuck half-in is not coming out.

**CHECK POLARITY on every pair before gluing.** Offer each magnet to its partner,
let it attract, mark that face, and glue it that way round. A reversed magnet
repels and will hold the cage off its seat.

### Guiding

Two things stop a sliding fit from being annoying:

- **Rails.** A `sled_rail_w` x `sled_rail_h` rib along each side of the cavity,
  with matching grooves in the sled. Without them the sled can rack diagonally
  and jam halfway.
- **A lead-in chamfer.** `sled_lead_cham` (1.5 mm) on the sled's leading edges so
  it self-centres instead of needing to be lined up by eye.

Clearance is `sled_slide_gap` (0.35 mm) **per side**. Print a 20 mm test stub of
the cavity and the sled nose first and check the fit before committing to an
8-hour print of the body.

Add a finger notch (`sled_finger_w` x `sled_finger_h`) to the sled face, or the
magnets will hold better than your fingernails can pull.

### Screw threads

If you fit the optional locking screws, use **M3 heat-set brass inserts**
(`insert_d`, `insert_z`), not self-tapping screws into bare plastic. Self-tapped
threads in PLA survive perhaps five or six cycles before stripping, and this is
a part designed to come apart repeatedly.

---

## 7. Speaker and the head

```
     ear grille   ear grille
         ░░           ░░       <- 13 holes each, in the stippled inner-ear dish
          \           /
        ┌──────────────┐
        │     head     │   <- front chamber (ellipsoid void, hollow)
        │   (hollow)   │
        └──────┬───────┘
          ═════╪═════       <- neck chimney (48 x 34), airtight
        ┌──────┴───────┐
        │  speaker on  │
        │   cage top   │   <- cage interior = sealed rear volume
        └──────────────┘
```

- Speaker mounts to the **top** of the cage, firing up, held by four M3 screws or
  a printed retaining ring.
- The stadium opening (`spk_grille_l` x `spk_grille_w`) in the cage top, with the
  gasket compressed between flange and roof.
- Sound then runs **cage top -> neck chimney -> hollow head -> ears**. The grille
  is *not* on the face: it is cut into the sculpted **stippled inner dish of each
  ear** (13 holes per ear, about 2.61 mm on the current 108.7% body,
  hex 4/5/4, on the dish's own major axis), fed by a
  shallow plenum under the skin and three ducts into the head void. See
  `panda_head_vents()` / `ear_vent()` in `panda.scad` and
  `previews/panda_ear_grille.png`. Open areas are matched (grille about 69.5 mm^2 per
  ear vs ~64.5 mm^2 of duct throat on the 108.7% body).
- `helpers.scad`'s generic `speaker_grille()` is unused - the ear grille is
  solved against the sculpt's own geometry instead.
- Keep the head cavity as sealed as practical. Every unintended gap is bass
  leaking out.
- Do not let the speaker's magnet sit against the DS3231 or the OLED ribbon.

---

## 8. Port access

| Port | Where | Why |
| --- | --- | --- |
| USB-C | Slot in the body's rear, aligned with the sled's ESP32 | Reflash and power without removing the sled |
| microSD | Slot in the **base cover**, under the DFPlayer | Changeable without opening anything |
| Joystick | Bore in the body's rear, at panda Z50 | The one control; stalk cap presses in from outside |
| Amp vents | Slots low on the body's back | The DFPlayer's amp runs warm in a sealed box |

Make the USB-C opening `esp_usb_w`/`esp_usb_h` plus `fit_gap`, and **oversize it
generously** - a couple of mm of slop is invisible from the front and saves a
reprint when the sled sits 1 mm deeper than modelled. Remember the plug body is
much larger than the receptacle: leave a shallow recess around the slot, or a
chunky cable's moulding will hold the sled out by a millimetre or two.

### How the charge cable actually gets out - READ THIS BEFORE BUYING A CABLE

There is exactly **one** USB opening: a slot on the cage's **back wall** (cage Z22)
with a matching hole through the rump. The cable enters **horizontally from behind**,
at the height of the panda's lower back. It does **not** come out of the base - the
base would put the cable under the panda, where it gets pinched and where the panda
then will not sit flat.

The other opening in the base cover is the **microSD slot**, under the DFPlayer.
Different hole, different job.

The ESP32 is portrait on the left wall with its USB-C facing **down**, so its
receptacle mouth is at cage Z21.9 - and on the 200 mm host there are 21.9 mm below
it before the cover ledge. A **straight** USB-C plug's moulding is 15-20 mm long, so
for the first time it simply fits: the plug hangs down inside the cage and the cable
turns out through the slot. (At 160 mm the mouth was at cage Z6.5, on top of the
ledge, and a straight plug would have run out through the base cover into the table.)

Two upgrades are still worth considering:

1. **A right-angle USB-C cable.** The plug turns at the board edge and lies flat,
   pointing back at the slot. Buy one that exits toward the *back*, not the side.
   It is tidier than a straight plug and puts less leverage on the socket.
2. **A panel-mount USB-C breakout in the slot** (best). The slot is deliberately
   sized to `usb_flange_w`/`usb_flange_h` for exactly this, and two bosses are
   already there for its screws. A short internal lead reaches the ESP32, the
   external cable plugs into the panda's back, and the strain relief lands on the
   printed part instead of on the ESP32's surface-mount socket.

Option 2 also solves the strain-relief problem below, and means a stiff cable can
never lever the cage out of its magnets.

`esp_usb_out` is how far the receptacle overhangs the PCB edge, which sets how
far back the ESP32 has to sit so the connector lands flush with the body wall.

### Choose the wall charger with care (USB-C specific)

Many CP2102 dev boards with a USB-C socket **omit the two 5.1 kohm CC pull-down
resistors**. A proper USB-C source will then never enable its output, and the
board simply stays dead on a C-to-C cable while working perfectly on A-to-C.

Yours currently runs from a Mac, so if that is over a C-to-C cable the resistors
are present and any charger will do. If it is A-to-C, **test your intended wall
charger and cable before the enclosure is closed** - discovering this with the
sled glued in is miserable. The workaround is an A-to-C cable, or soldering the
two resistors from CC1 and CC2 to ground.

### Strain relief on the USB lead

The USB-C socket is soldered to the ESP32 PCB with small surface-mount pads, and
it is the only thing tethering the clock. A yank on the cable tears the socket
off the board - this is the most likely way to kill the finished clock. Add a
printed clamp or a zip tie anchored to the body, so any pull lands on the
enclosure and not on the connector.

---

## 9. Cable routing inside the sled

- Leave a **service loop**: enough slack that the sled roof lifts off and lies
  beside the base without anything under tension.
- Heat-shrink over every solder joint, including the speaker terminals.
- Anchor bundles with adhesive tie-downs or printed loops so nothing rests on
  the DFPlayer's SD slot or the joystick's moving gimbal.
- Nothing should touch the joystick body - it must be free to tilt. Note the cage
  is built for `joy_use_tilt` (11 deg, plenty for d-pad use), **not** the stick's
  full `joy_throw_a` of 23: the printed cap and the rump bore are sized to 11.

---

## 9a. Fitting the joystick and closing the base

The joystick is on the **rump**, not the belly, and it bolts to the **OUTSIDE** of
the cage's back wall - so it goes on before the cage goes in. Order matters here:

1. Solder flying leads to the KY-023's 5-pin header. Unlike the old design you do
   **not** have to desolder or flatten it: the header faces outward into the rump,
   and the wires come back through a slot in the wall just below the board.
2. Bolt the PCB to the four **standoffs on the back wall's outer face**, through the
   module's own four holes (19.85 x 19.80). The gimbal points **away** from the
   wall, into the rump; fit it with the gimbal's wide (23.40 mm, nub) axis running
   **across X**, so the PCB's 32.30 mm dimension is horizontal. Four M3 self-tappers
   from the rump side; do not overtighten a 0.92 mm PCB.
3. Route the five leads through the wire slot under the board and into the cage.
4. **Do not fit the thumb cap yet.** It presses on from *outside* the panda, once
   the cage is in.
5. Slide the cage up into the body. The whole assembly stands **14.68 mm** proud of
   the cage's back face, far more than the base hatch clears, so it rides up the
   **insertion channel** moulded into the rump. The revised body also has a narrow
   groove for the bare shaft, which reaches another 5.95 mm beyond the gimbal.
   Keep the stick centred during insertion and use the orientation in step 2.
   The v2 body has the broad deep recess on the LEFT when looking at its back
   and allows 3 mm more PCB spacing than the nominal 2 mm stand-off.
   The older STL missed the shaft's travel and could catch even when oriented
   correctly; see the assembly-relief notes in `enclosure/README.md`.
   The v3 body also removes the catching lip between the feet and adds a 0.8 mm
   entrance lead-in. Higher corner shaping beside the paws is retained to avoid
   wall holes; the entrance check does not guarantee a friction-free full stroke.
6. For the **217.4 mm v8 body**, print and fit **`joy_cap_scaled_body`** through the
   unchanged rump bore. Its 20 mm stalk reaches the enlarged back; the older
   11 mm `joy_cap` is only for the 200 mm bodies. The keyed socket is unchanged.
   Print the 4 mm neck solid, test movement before gluing, then secure with a
   small drop of CA. The oval socket keys it against rotation; if it will not
   seat, rotate it 90 degrees. The new cap has been checked geometrically, not
   strength-tested as a physical print.
7. Thread the USB-C lead out of the **rear slot** and fit the printed **`cover`**
   over the base: 6 self-tappers up into the ledge inside the walls. The cover has
   a microSD slot under the DFPlayer and a finger notch at the front - check you
   can get a card in and out **before** you glue anything.

**Printing the cover.** It is no longer a flat plate: its outer surface is the
panda's own domed base, so it is ~7 mm thick at the rim and thinner in the middle.
Print it **flat face down** (the machined-looking side on the bed, dome upward) and
it needs no supports. Fitted, its lowest point clears the table by ~0.8 mm, so the
panda still stands on its own feet.

The v8 body **uniformly enlarges the whole original panda to 108.7%**, reduced
from v6's 115%. It measures **157.3 × 150.2 × 217.4 mm (W/D/H)**; print at **100%
slicer scale** so the cavity stays the same size. The cage, cover, mounting
positions and hardware cuts remain unchanged. The minimum modeled notch wall
above the flange seat is **1.019 mm**; going to 108.6% would leave less than 1 mm.
The round outer shape is preserved and the underside remains open for insertion.
Use the matching 20 mm cap from step 6. The known small higher front-corner snags
remain; the repaired entrance is clear in the model. V8 also opens a short internal
transition above the speaker so its full offset grille feeds the central chimney.
The printed cage and the v7 20 mm cap stay unchanged.

---

## 10. Final checks before it goes on the bedside table

1. Overnight soak; confirm `[hb]` heartbeats every 60 s and free heap flat
   (`soak/soak_logger.py` does this and writes a log).
2. Pull the USB for 30 s, replug: time must survive and the log must **not** say
   "RTC power was lost".
3. Volume at maximum: no buzz, no rattle, no pop between clips.
4. Set a quiet-hours window that starts in two minutes; confirm announcements
   stop, and that a stick-left tap still speaks.
5. Slide the sled out and in ten times; nothing snags, nothing loosens.
6. Set the DST region and confirm the displayed time does not move.

---

## 11. Modelling status

The enclosure is no longer a massing model - `cage.scad` and `panda.scad` export
printable geometry, and `enclosure/verify_cage.py` asserts the mounts are real.

Done:

- [x] **Host: the de-embossed sculpt at 200 mm**, with the import transform derived
      from the mesh instead of hand-fitted (`refit.py` re-derives everything)
- [x] Cage shell 75 x 80 x 88, base flange, magnet pockets; `shell_prof` **solved**
      against the sculpt including its per-height front setback (`fit_shell.py`
      computes it - do not hand-tune it)
- [x] OLED window + 4 mounting bosses, all on flat wall, screen 15.7 mm deep
- [x] Joystick on the rump: four standoffs on the back wall's **outer** face, stalk
      cap, stepped insertion channel through the body
- [x] ESP32 / RTC / DFPlayer mounts + retention bars; a **straight** USB-C plug now
      fits below the ESP32
- [x] Speaker throat, head resonator, neck chimney and ear grilles
- [x] Base hatch and rebate, **base cover** (clipped to the sculpt's domed base) and
      its ledge
- [x] USB-C exit - in the cage **and** in the body
- [x] `breach` fit-check renders empty; `verify_cage.py` and `verify_window.py` green

Open:

- [ ] The measurements in [`MEASUREMENTS.md`](MEASUREMENTS.md) section 9. The OLED
      header's position is the one that matters: it currently costs 5 mm of screen
      depth purely because nobody knows which edge it is on.
- [ ] **The screen sits ~16 mm behind the belly surface.** The belly skin over the
      window is at panda Y53.8 and the glass lands at Y37.2. The cage cannot simply
      move forward - past `cage_yfront` 46 the flat wall the OLED needs collapses
      (run `fit_shell.py --yfront 48` to see it). Options are a forward pedestal
      through the front wall, or relieving the header so the standoff drops to 2 mm.
- [ ] Print-splitting and orientation
- [ ] Amp vents

Dimensions for all of the above are now in `dimensions.scad`. Before the final
export, work through [`MEASUREMENTS.md`](MEASUREMENTS.md) with calipers and
replace the `[verify]` values with your actual parts - clones vary by a couple of
mm, which is the difference between a snug fit and a reprint.

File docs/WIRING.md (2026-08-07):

# Vocetempo - Full Wiring Reference

This is the complete wiring for the finished v1 clock. Build it once on the
breadboard and every remaining software stage will work against it.

> Power everything from the ESP32's regulated rails:
> - **3V3** pin -> breadboard "+" rail (3.3 V) for the I2C devices and the joystick
> - **5V / VIN** pin -> a second "+" rail (5 V) for the DFPlayer only
> - **GND** pin -> breadboard "-" rail (shared ground for EVERYTHING)
>
> A shared ground is essential: every device must reference the same GND or
> nothing works reliably. Only the DFPlayer goes on 5 V.

For assembling this permanently - soldering order, the slide-out sled, and the
speaker mount - see [`ASSEMBLY.md`](ASSEMBLY.md).

## Pin map (ESP32 -> component)

| ESP32 pin | Goes to | Notes |
| --- | --- | --- |
| 3V3 | + rail (3.3 V) | Powers OLED + RTC |
| 5V (VIN)  | + rail (5 V) | Powers DFPlayer |
| GND | - rail (ground) | Shared by ALL devices |
| GPIO 21 | I2C SDA (OLED + RTC) | Shared data line |
| GPIO 22 | I2C SCL (OLED + RTC) | Shared clock line |
| GPIO 27 | DFPlayer RX (via 1k resistor) | ESP32 TX -> DFPlayer RX (30-pin board lacks 16/17) |
| GPIO 14 | DFPlayer TX | ESP32 RX <- DFPlayer TX |
| GPIO 32 | Joystick VRx | analog, ADC1_CH4 |
| GPIO 33 | Joystick VRy | analog, ADC1_CH5 |
| GPIO 25 | Joystick SW | press-down switch -> GND, internal pull-up |
| GPIO 26 | *free* | was Button BACK; spare for v2 |
| GPIO 2 | onboard LED | built-in, no wiring |

## Per-device wiring

### OLED (SSD1309, I2C) - 3.3 V
| OLED | Rail / ESP32 |
| ---- | --- |
| GND  | - rail |
| VDD  | + rail (3.3V)|
| SCL  | GPIO 22 |
| SDA  | GPIO 21 |

### DS3231 RTC (I2C) - 3.3 V
| RTC  | Rail / ESP32 |
| ---- | --- |
| GND  | - rail |
| VCC  | + rail (3.3V)|
| SDA  | GPIO 21 |
| SCL  | GPIO 22 |
(SQW and 32K pins unused. Onboard AT24C32 EEPROM appears at I2C 0x57.)

### DFPlayer Mini (UART) - 5 V
| DFPlayer pin | Connect to |
| --- | --- |
| VCC | + rail (5 V) |
| GND | - rail |
| RX | GPIO 27 **through a 1k resistor** |
| TX | GPIO 14 |
| SPK_1 | speaker wire 1 |
| SPK_2 | speaker wire 2 |
(Use SPK_1/SPK_2 for the bare speaker. Do NOT use DAC_L/DAC_R for a passive
speaker. microSD card goes into the DFPlayer, not the ESP32.)

### Speaker (CQRobot 3W 4ohm)
| Speaker | Connect to |
| --- | --- |
| wire 1  | DFPlayer SPK_1 |
| wire 2  | DFPlayer SPK_2 |

IMPORTANT - the DFPlayer output is MONO and BRIDGE-TIED (BTL):
- SPK_1 and SPK_2 are the TWO TERMINALS OF ONE SPEAKER, not left/right.
- NEITHER pin is ground. Do NOT connect a speaker wire to GND.
- Do NOT tie SPK_1 and SPK_2 together.
- Use ONE speaker across SPK_1/SPK_2. (Two speakers only in SERIES = 8 ohm;
  never in parallel = 2 ohm, which overheats the amp.)
- Polarity does not matter for a single speaker.
- Wiring a speaker pin to GND or shorting SPK_1+SPK_2 shorts the 8002B amp
  and makes it overheat.

### Joystick (KY-023 analog thumbstick) - 3.3 V
Replaces the four push buttons. Five pins, and the labels vary slightly between
batches (`VRx`/`VRy` are sometimes `X`/`Y`, `SW` sometimes `SEL` or `B`).

| KY-023 pin | Connect to | Notes |
| --- | --- | --- |
| GND | - rail | shared ground |
| +5V / VCC  | **+ rail (3.3 V)** | see the warning below - NOT the 5 V rail |
| VRx | GPIO 32 | analog axis |
| VRy | GPIO 33 | analog axis |
| SW | GPIO 25 | shorts to GND when pushed down |

> **Power it from 3.3 V, even though the pin says "+5V".**
> The axes are potentiometer dividers across whatever you feed them, so on 5 V
> they would swing to 5 V and be fed straight into a GPIO. The ESP32's ADC pins
> are 3.3 V devices: anything above ~3.3 V reads pinned at maximum and risks
> damaging the pin. The module has no regulator and works perfectly on 3.3 V -
> the only effect is that full deflection reads 4095 instead of clipping.

No external resistors are needed. `SW` uses the ESP32's internal pull-up
(`INPUT_PULLUP`), so it reads HIGH idle and LOW when pressed, exactly like the
buttons it replaces. The two axis pins get no pull-up - that would fight the
potentiometer.

**Action mapping** (`include/Buttons.h`):

| Stick movement | Logical action | Effect on the clock face |
| --- | --- | --- |
| up / down | UP / DOWN | pet the panda; scroll in menus |
| left | BACK | tap speaks the time, hold mutes |
| right | OK | open the menu / confirm |
| push down (click) | OK | same as right |

**Confirm the orientation after wiring** - which way each potentiometer swings
depends on how the module is mounted:

```sh
pio run -e joystick_test -t upload
pio device monitor -b 115200
```

Idle should read `x` and `y` near 1900-2100 with `dir=None`, and `sw=1` falling
to `0` when clicked. Push the way you want "up" to mean: if it prints `Down`,
set `kInvertY = true` in `src/Buttons.cpp`; if left/right are swapped, set
`kInvertX = true`. If pushing up prints `Left`/`Right`, the two axis wires are
swapped - exchange VRx and VRy.

## I2C addresses on the bus
- `0x3C` - OLED display
- `0x68` - DS3231 RTC
- `0x57` - AT24C32 EEPROM (on the RTC board; unused in v1)

## Safety notes
- Wire with USB unplugged; plug in only when a step is complete.
- I2C devices on 3.3 V; DFPlayer on 5 V; everything shares GND.
- The 1k resistor on DFPlayer RX protects its input and improves reliability.

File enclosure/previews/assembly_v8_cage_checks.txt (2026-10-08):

13710 facets   X -48.50..48.50   Y -53.50..48.00   Z 0.00..80.00

   ok  cage height 80.00 == 80.0
-- OLED bosses (PCB face must be at y -35.00) --
   ok  boss x -32.15 cageZ 16.20: wall front -44.00 (want -44.00 - full flat wall)
   ok  boss x +32.15 cageZ 16.20: wall front -44.00 (want -44.00 - full flat wall)
   ok  boss x -32.15 cageZ 59.20: wall front -44.00 (want -44.00 - full flat wall)
   ok  boss x +32.15 cageZ 59.20: wall front -44.00 (want -44.00 - full flat wall)

-- OLED envelope (PCB + its 6.32mm header must be unobstructed) --
   ok  nothing intrudes into the OLED's y-band (-35.00..-27.70)

-- joystick standoffs, OUTSIDE the back wall (cage Z43.0) --
   ok  standoff x-13.00 cageZ 33.08: face at y46.00 (found [42. 46.])
   ok  standoff x-13.00 cageZ 52.92: face at y46.00 (found [42. 46.])
   ok  standoff x+13.00 cageZ 33.08: face at y46.00 (found [42. 46.])
   ok  standoff x+13.00 cageZ 52.92: face at y46.00 (found [42. 46.])
   ok  wire slot is open through the back wall
   ok  no plinth/pocket left on the inner face behind the joystick

-- speaker ear bosses (pilot must be open at the bottom face) --
   ok  speaker boss (-31.8, -2.6): pilot open from below
   ok  speaker boss (-31.8,+18.6): pilot open from below
   ok  speaker boss (+31.8, -2.6): pilot open from below
   ok  speaker boss (+31.8,+18.6): pilot open from below

-- joystick pilot depth (want >= 3.3mm; blind, not through) --
   ok  pilot (-13.0,z 33.1): usable depth 3.50mm (blind at y42.50)
   ok  pilot (-13.0,z 52.9): usable depth 3.50mm (blind at y42.50)
   ok  pilot (+13.0,z 33.1): usable depth 3.50mm (blind at y42.50)
   ok  pilot (+13.0,z 52.9): usable depth 3.50mm (blind at y42.50)

-- base hatch --
   ok  base is open at (0,10) [centre]
   ok  base is open at (0,-20) [centre-front]
   ok  base is open at (20,-10) [front-right]

-- base-cover ledge --
   ok  ledge material beside screw (+33.0,  +0.0)
   ok  ledge material beside screw (-33.0,  +0.0)
   ok  ledge material beside screw (+25.0, -38.5)
   ok  ledge material beside screw (-25.0, -38.5)
   ok  ledge material beside screw (+25.0, +40.0)
   ok  ledge material beside screw (-25.0, +40.0)

-- side-wall boss tops (should stand SO_SIDE off the inner face) --
   ok  ESP32 lower: boss face near x-23.50 (found [-37.5 -23.5  35.5  37.5])
   ok  ESP32 upper: boss face near x-23.50 (found [-37.5 -23.5  35.5  37.5])
   ok  RTC far hole: boss face near x+23.50 (found [-37.5 -23.5  23.5  37.5])

ALL CHECKS PASSED

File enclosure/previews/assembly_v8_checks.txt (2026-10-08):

PASS current cage source equals already-printed cage: 0.000000 mm^3
PASS v7 overall size and ground plane unchanged
PASS body is one closed, consistently oriented solid
PASS no added material/obstructions: 0.000013 mm^3
PASS only speaker inlet changed: 0.000020 mm^3 outside inlet
PASS speaker correction stays inside outer skin: nearest removed vertex 37.938 mm inside
INFO removed 580.715 mm^3 inside speaker transition only.
PASS OLED aligned at X0/Z47.8: 8188/8192 pixel centres visible; only 4 original rounded corners masked
PASS printed cage screen cut clears all 8192 pixel sight lines
PASS entire offset speaker aperture clear: 0.000000 mm^3 (v7 obstruction 142.541)
PASS speaker inlet, chimney, head chamber and both ear ducts form one connected air path
PASS connected sound path has no body obstruction: 0.000068 mm^3
PASS all 26 ear vent centres open from outside into their plenums: 0 blocked
PASS USB slot aligned through body: 0/589 blocked access rays
PASS USB slot aligned through printed cage: 0/589 blocked access rays
INFO run companion cage, joystick and uniform-body checks for mounting pilots, insertion, magnets and cap tilt.
PASS archive CRC and every archived STL match the current files.
PASS existing cage/cover/bars/cap and frozen v7 body hashes unchanged.
SHA256 panda_body_uniform_v8.stl 220ba07d7753083b2f96bede6821568c68caace10a8ec932fa273a7e83edd210
SHA256 cage.stl f5bec98a6ac82bf0fac670d4038dd3ed6256401ee2749c2013fd0266745b05d7
SHA256 joy_cap_scaled_body.stl 2913c98afb45c4a4dc35b26556cc66f90c59e375e15e1a13919c6bce4a2713b4
PASS already-printed cover / body overlap: 0.000000 mm^3 (cover at panda Z0..7).

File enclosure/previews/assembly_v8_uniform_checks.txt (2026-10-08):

PASS body: closed mesh with consistent orientation
PASS body: one connected solid
PASS cap: closed mesh with consistent orientation
PASS cap: one connected solid
PASS outer blank is exactly 108.7% original sculpt: 0.000000 mm^3 difference
PASS body dimensions [157.28, 150.182, 217.4] mm (X/Y/Z), feet at Z0
PASS no patch or bulge outside the uniformly scaled sculpt
PASS all fixed hardware cutters clear: 0.000492 mm^3 overlap
PASS existing magnet seat/support (38,50) retained: 0.000000 mm^3 lost
PASS existing magnet seat/support (-38,50) retained: 0.000000 mm^3 lost
PASS existing magnet seat/support (44,17) retained: 0.000000 mm^3 lost
PASS existing magnet seat/support (-44,17) retained: 0.000000 mm^3 lost
PASS minimum channel wall above flange seat: 1.019302 mm at [-21.44, -64.424, 11.2], 20836 samples (intended ports excluded)
PASS existing cage seats without overlap
PASS feet entrance clear at 353 poses: 0.000000 mm^3
PASS higher corner overlap unchanged: 5.777457 mm^3 (previous 5.777457)
PASS long cap tilt clear in 1152 poses: 0.000000 mm^3 maximum overlap
PASS cap still clears with 10% radial enlargement: 0.000000 mm^3 overlap
INFO 217.4mm print height required. Use the matching scaled-body cap; the original 11mm cap is too short.
INFO underside stays open; original higher corner interference remains. Physical fit and cap strength are not certified.

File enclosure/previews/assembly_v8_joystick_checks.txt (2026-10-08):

PASS closed mesh with consistent face orientation and positive volume
PASS one connected body
PASS printed cage overlap: 0.000002 mm^3
PASS PCB + extra gap insertion overlap: 0.000000 mm^3
PASS gimbal + extra gap insertion overlap: 0.000000 mm^3
PASS bare shaft + extra gap insertion overlap: 0.000000 mm^3
PASS right header + extra gap insertion overlap: 0.000000 mm^3
PASS left header + extra gap insertion overlap: 0.000000 mm^3
PASS deep rear-left side allowance insertion overlap: 0.000000 mm^3
PASS no unintended rear openings above entrance: 0 missing samples
PASS rear wall above entrance: minimum 6.667 mm at [-1.75, -67.43, 25.0], 7558 samples (openings excluded)

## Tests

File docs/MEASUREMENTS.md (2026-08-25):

# Vocetempo - Component Measurement Sheet

Fill in the **Yours** column, then the values go into `enclosure/dimensions.scad`
and the enclosure can be modelled against real parts instead of catalogue
numbers. Clones vary by a couple of mm, which is exactly the difference between
a case that closes and a reprint.

Everything is in **millimetres, to 0.1 mm**. Your caliper reads 0.01 mm, but an
FDM printer holds maybe ±0.2 mm, so extra digits are false precision.

---

## Before you start

**1. Zero it.** Close the jaws fully, press ZERO. Open and close again - it must
return to `0.00`. If it drifts, the battery is low.

**2. Sanity-check it against something you already know.** The best free
standard in the box is a **pin header's plastic base**: it is moulded as exactly
`N x 2.54 mm` (the bodies butt together so strips can be ganged), and unlike the
pins themselves it cannot bend.

Count the pins, measure the plastic base outer-to-outer, and it should read
`N x 2.54`. A 15-pin strip must give **38.1 mm**. Within 0.1 mm and the caliper
is good enough for everything here.

Do NOT calibrate against the pins - they lean, and the end ones leaning inward
reads short. If you do want to use them, remember the pitch is measured
centre-to-centre, so outer-to-outer is `2.54 x (N-1) + one pin width`.

> Lesson that applies everywhere below: **trust rigid references.** PCB edges,
> moulded plastic bodies and machined features measure repeatably. Pins, wires,
> thumb caps and speaker cones do not - treat those as approximate.

**3. Use the right part of the tool.**

| Feature | Use |
| --- | --- |
| Board length, width, thickness | Large lower jaws (outside) |
| Hole and slot diameters | Small upper jaws (knife edges, inside) |
| How far a connector sticks out | Depth rod (the tail that slides out the end) |
| Height of a part above its PCB | Depth rod, or the step on the back of the jaw |

**4. Light pressure.** PCBs are rigid, but thumb caps, foam and the speaker cone
compress. Squeeze hard and you will record a part smaller than it is, then print
a hole it does not fit through.

**5. Measure twice, in two places.** Boards warp and caps are never perfectly
round. For anything that needs **clearance** (holes, cutouts, cavities) record
the **larger** reading. For anything that needs a **press fit** (magnet pockets)
record the **smaller**.

---

## The centre-to-centre trick

You cannot put jaws on the middle of two holes, but mounting-hole spacing is
exactly what standoffs need. So measure edge to edge and correct:

```
   |<--------- A --------->|      A = outer edge to outer edge
   (  O  )           (  O  )
      |<----- C ----->|            C = A - d   (d = one hole diameter)
        |<--- B --->|              B = inner edge to inner edge
                                   C = B + d   <- same answer, use it to check
```

Do it **both ways**. If `A - d` and `B + d` disagree by more than 0.2 mm, one of
the readings slipped.

---

## Heights matter more than footprints

The usual mistake is measuring X and Y for everything and forgetting Z. The sled
depth is set by the **tallest thing in the stack**, which is likely the joystick
cap or the speaker.

Rather than adding up parts and hoping, **plug a module into its socket on the
perfboard and measure the whole assembled stack in one go**: perfboard underside
to the top of the tallest component. Do that for each module. Those four numbers
size the sled.

---

## 1. OLED - Hailege 2.42" SSD1309

For the active area, run the panel test first - it forces **every pixel on**, so
you can see the exact lit rectangle instead of guessing where the glass ends:

```sh
pio run -e oled_test -t upload
```

Then measure the **lit area**, and the gap from each PCB edge to the lit edge.
That gives size and position in one pass, which is what the window cutout needs.

| What | Variable | Nominal | Yours | How |
| --- | --- | --- | --- | --- |
| PCB width | `oled_pcb_w` | 72 | **68.63** | outside jaws |
| PCB height | `oled_pcb_h` | 40 | **46.60** | |
| PCB thickness | `oled_pcb_t` | 1.4 | **0.98** | ignore components |
| Glass width | `oled_glass_w` | 65 | **62.30** | the black panel, not the PCB |
| Glass height | `oled_glass_h` | 37 | **39.90** | at widest; ~1mm notch bottom-middle |
| **Lit area width** | `oled_active_w` | 55.0 | **55.0** | confirmed with `oled_test` |
| **Lit area height** | `oled_active_h` | 37.0 | **28.0** | confirmed; old 37.0 was impossible |
| PCB left edge to lit edge | *(for `oled_active_dx`)* | - | **7.35** | |
| PCB right edge to lit edge | *(for `oled_active_dx`)* | - | **7.35** | -> centred in X, dx=0 |
| PCB top edge to lit edge | *(for `oled_active_dy`)* | - | **6.2** | |
| PCB bottom edge to lit edge | *(for `oled_active_dy`)* | - | **12.6** | -> lit 3.1mm ABOVE centre, dy=+3.1 |
| Mounting hole spacing, horizontal | `oled_hole_dx` | 66 | **64.3** | edge-to-hole method (see below) |
| Mounting hole spacing, vertical | `oled_hole_dy` | 34 | **43.0** | |
| Mounting hole diameter | `oled_hole_d` | 3.0 | **2.5** | inside jaws |
| **Total depth, glass front to tallest thing on the back** | `oled_depth_hdr` | - | **12.55** | 6.23 bare, +6.3 for soldered header |

Give me all four edge-to-lit gaps and I will compute `oled_active_dx`/`dy`
myself - it is easy to get the sign wrong by hand.

> **Hole spacing without wedging jaws into a 2.5mm hole.** The centre-to-centre
> trick above assumes you can get a clean rim-to-rim reading; in a small hole the
> knife-edges over-read badly (we got 2.72 for a 2.5mm hole). What actually
> worked: measure **board edge -> near wall of the corner hole (A)** and
> **board edge -> far wall of the same hole (B)** with the big jaws closing on a
> flat gap. Then `centre-from-edge = (A+B)/2`, and by symmetry
> `spacing = board_dimension - (A+B)`. Cross-check: `B - A` must equal the hole
> diameter. This gave H: A=1.00,B=3.34 -> 68.63-4.34 = 64.3; V near-to-near=40.50
> -> +2.5 = 43.0. Both leave a sane wall to the edge, unlike the old 66/34.

## 2. ESP32 DevKit (DollaTek, CP2102) - MEASURED

| What | Variable | Nominal | Yours | How |
| --- | --- | --- | --- | --- |
| Board length | `esp_w` | 52 | **53.20** | |
| Board width | `esp_h` | 28.5 | **28.40** | |
| PCB thickness | `esp_t` | 1.6 | **1.45** | |
| USB-C shell width | `esp_usb_w` | 9.0 | **8.80** | across the metal shell |
| USB-C opening height | `esp_usb_h` | 3.2 | **3.10** | the port opening, for the wall cutout |
| USB-C stick-out past PCB | `esp_usb_out` | 1.5 | **1.5** | depth rod |
| Pin length below the board | `esp_pin_drop` | 10 | ~10 | |
| Tallest top-side part | `esp_top_h` | - | **4.63** | chip = USB-C height |

> No mounting holes -> **printed snap-in cradle** (pocket 53.2 x 28.4 + tabs).
> Note `esp_top_h` (board surface to top = 4.63) is NOT the USB opening height
> (3.10) - the shell doesn't start at the PCB face. Both are recorded separately.

## 3. DS3231 RTC (ZS-042) - MEASURED

| What | Variable | Nominal | Yours | How |
| --- | --- | --- | --- | --- |
| Board length | `rtc_w` | 38 | ~38 | ~nominal confirmed |
| Board width | `rtc_h` | 22 | ~22 | ~nominal confirmed |
| PCB thickness | `rtc_t` | 1.6 | **1.58** | |
| Battery holder diameter | `rtc_batt_d` | 20.5 | **21.63** | |
| Battery holder height above PCB | `rtc_batt_z` | - | **7.80** | tallest part; needs finger room to swap |
| Mounting hole diameter | `rtc_hole_d` | - | **2.30** | 3 holes: 2 by pins, 1 top corner |

> Battery is on the component side, top edge. **3 holes, not 4** - exact
> positions to be lifted from the photo when the RTC mount is designed.

## 4. DFPlayer Mini - MEASURED

| What | Variable | Nominal | Yours | How |
| --- | --- | --- | --- | --- |
| Module length | `dfp_w` | 21.6 | **20.70** | |
| Module width | `dfp_h` | 20.2 | **20.20** | |
| PCB thickness | `dfp_t` | 1.6 | **2.00** | |
| Tallest part above PCB | `dfp_top_h` | - | **4.96** | |
| SD slot mouth width | `dfp_sd_w` | 12 | **11.20** | |
| SD slot mouth height | `dfp_sd_h` | 1.6 | **0.86** | card thickness |

> SD slot and pin headers exit the **same edge** - keep it accessible. Only a
> half-slot on the opposite edge (no usable holes) -> **printed snap-in clip**.

## 5. Speaker - ENCLOSED BOXED UNIT (not a bare driver) - MEASURED

The nominal was for a 40mm round driver; the real part is a **rectangular boxed
speaker with 4 mounting ears** and flying leads.

| What | Variable | Nominal | Yours | How |
| --- | --- | --- | --- | --- |
| Body length (no ears) | `spk_box_l` | - | **51.25** | |
| Body width | `spk_box_w` | - | **30.90** | |
| Overall length (ear tip to tip) | `spk_overall_l` | - | **69.50** | ears on the length axis only |
| Total depth | `spk_h` | 6 | **16.38** | grille face to back |
| Grille opening (stadium) long | `spk_grille_l` | - | **37.35** | |
| Grille opening (stadium) short | `spk_grille_w` | - | **26.80** | |
| Ear hole diameter | `spk_ear_hole_d` | - | **3.20** | M3 |
| Ear spacing, long axis | `spk_ear_dx` | - | **63.60** | 60.4 n-to-n + 3.2 |
| Ear spacing, short axis | `spk_ear_dy` | - | **21.20** | |

> **Mounts to the TOP of the cage, grille UP, firing into the panda's HEAD
> chamber.** Head is the resonating port; vents out the face. All wiring stays
> on the cage. Grille and ears are on the same (up-facing) face.

## 6. Joystick (KY-023) - MEASURED

| What | Variable | Nominal | Yours | How |
| --- | --- | --- | --- | --- |
| PCB width | `joy_pcb_w` | 26 | **26.70** | |
| PCB height | `joy_pcb_h` | 34 | **32.30** | |
| PCB thickness | `joy_pcb_t` | 1.6 | **0.92** | |
| Gimbal body, narrow axis | `joy_body_w` | 24 | **19.80** | not square! |
| Gimbal body, wide axis | `joy_body_w2` | - | **23.40** | has a protruding nub |
| Gimbal body height above PCB | `joy_body_h` | 20 | **11.76** | |
| Widest flange diameter | `joy_flange_d` | - | **26.0** | THE part the cone must clear |
| Flange height above PCB | `joy_flange_z` | - | **12.0** | |
| Thumb cap diameter | `joy_cap_d` | 20 | **26.0** | |
| Cap top height above PCB | `joy_cap_z` | 32 | **29.43** | tallest thing in the whole build |
| Tilt half-angle | `joy_throw_a` | 25 | **23** | ~12.5mm cap sweep -> atan(12.5/29.43) |
| Mounting hole spacing (across 26.70 width) | `joy_hole_dx` | 20 | **19.85** | |
| Mounting hole spacing (along 32.30 length) | `joy_hole_dy` | 28 | **26.0** | CORRECTED 2026-08-24; the earlier 19.80 was the gimbal body width misread as a pitch |
| Mounting hole diameter | `joy_hole_d` | 3.0 | **3.20** | M3 |
| Header extension past the PCB (long axis) | `joy_pin_ext` | - | **5.2** | 32.30 -> ~37.5 overall |
| Header height above the component face | `joy_pin_raise` | - | **~6** | pins rise ~5mm then BEND to run parallel to the board |

> The cone must clear the **26mm flange at z=12** at 23deg tilt, not just the
> narrow stick - compute the panel opening from both.

## 7. Mounting & hardware - MEASURED / DECIDED

**No perfboard.** Modules screw to printed standoffs/bosses on the cage (or
snap-in cradles for the ESP32/DFPlayer), wired point-to-point. **Self-tapping
screws into printed bosses** - NO heat-set inserts (so the boss hole is a pilot
sized for the screw's core, and hole positions are forgiving).

**Two screw sizes, not one.** M3 self-tappers fit every Ø3.2 hole: joystick (x4,
**M3x4 MAX** - the pilot is blind at 3.5 mm, a longer screw bottoms out before
the head seats), speaker ears (x4), retention bars (x4), base cover (x6). The
OLED's Ø2.5 and the RTC's Ø2.3 holes do **not** pass an M3 - those two use **M2
self-tappers** (x4 + x3) into a smaller pilot (`screw_hole_d_m2` = 1.7).

| What | Variable | Nominal | Yours |
| --- | --- | --- | --- |
| Magnet diameter | `magnet_d` | 6.0 | **5.0** |
| Magnet thickness | `magnet_t` | 3.0 | **3.0** |

> Cage retained by **magnet PAIRS** (cage + body). Check polarity before gluing
> every magnet (offer to partner, let attract, mark, glue) - a reversed magnet
> repels and the cage won't seat. Press-fit + CA glue. Steel-washer variables
> kept unused as a fallback.
>
> RTC hole positions were read from the photo (~+-1.5mm); fine for self-tapping
> bosses but confirm with calipers if the fit is tight.

## 8. Cage layout - DECIDED (revised 2026-08-21, 200 mm host)

Cage is **75 W x 80 H x 88 D mm**, sitting at panda Z7, front face at panda Y45.
One job per face:

| Face | Occupant |
| --- | --- |
| Front (belly) | OLED, **alone** |
| Back (rump) | **joystick, on the OUTER face**; DFPlayer (lower right) and the USB-C exit (lower left) inside |
| Left side | ESP32, portrait, USB-C edge down |
| Right side | RTC, on its 3 real holes |
| Top | speaker, grille up into the head |
| Base | open for assembly, then closed by the printed **base cover** |

Key derived positions (all from `enclosure/refit.py`, verified against the mesh):

| | value |
| --- | --- |
| host | `panda_original_without_embosses.stl`, 200 mm (`panda_scale` 212.9096, `panda_y_off` 9.036) |
| OLED lit-window centre | panda Z47.8 -> PCB spans cage Z14.4..61.0, bosses at Z16.2 / Z59.2 |
| screen recess | **15.7 mm** (10.7 if the left-edge header is desoldered) |
| joystick centre | panda Z50; assembly 14.68 mm proud of the back face; cap stalk 11.0 mm |
| rump depth at the joystick | 25.7 mm (26.1 at its deepest, panda Z36) |
| ESP32 | cage Z23.4..76.6; USB-C mouth at cage Z21.9, straight plug fits |
| magnets | cage (+-38, -49) and (+-44, -16) -> panda (+-38, 50) and (+-44, 17) |
| front wall | full Y45 through cage Z4..42, setback 0.86 -> 16.57 above cage Z62 |
| back wall | **full width at every height** (`cb` is 0 throughout) |

> The joystick was under the screen on the belly. **It does not fit there** - the
> OLED alone is 46.6 mm tall and the KY-023 adds 26.7 plus clearance. It moved to
> the rump, and with the re-fit it also turned round: it now bolts to standoffs on
> the OUTSIDE of the back wall through its own four holes, instead of dropping into
> a pocket behind a printed retention frame. See the placement block in
> `enclosure/dimensions.scad`.

---

## 9. STILL NEEDED - these block the next revision

Everything above is measured. These are not, and each one is currently a
*derived guess* that some real geometry depends on.

### OLED

| # | What | Why it matters | Current assumption |
| --- | --- | --- | --- |
| 1 | PCB **bottom** edge -> **glass** bottom edge | sets how much of the board is dead space; it is the number the whole belly-vs-rump budget turned on | **6.45** (derived by assuming the glass is centred on the lit area) |
| 2 | PCB **top** edge -> glass top edge | same, other end | 0.25 (derived) |
| 3 | ~~Which edge is the pin header on?~~ | **ANSWERED**: there are **TWO** headers on the back - one along the **top edge, centred**, and one down the **left edge** (viewed from the front, so cage **-X**). Either can be used | both protrude **6.32** (= `oled_depth_hdr` - `oled_depth_bare`) |
| 4 | How long is each header, and is the unused one removable? | decides whether the standoff can drop from 7mm to ~2 | assumed both populated and permanent |
| 5 | Ribbon/flex notch at the glass bottom-middle: width, and height above the PCB bottom edge | it must not be clamped or pressed | "~1mm slope/notch", position unknown |

> **Why the standoff is still 7mm.** 6.32mm of header behind the PCB does not fit a
> 4mm standoff in a 2mm wall - it would drive straight through the front wall and
> out of the screen window. Now that both header positions are known, a relief could
> be cut instead and the standoff dropped to ~2mm, buying back 5mm of screen depth.
> But only the **top-middle** one is cheap to relieve: it sits in the 6mm band
> between the window's top edge (cage Z54.3) and the PCB's top edge (Z60.2), clear
> of the mounting bosses. The **left-edge** header runs down cage X-33, right
> through the boss column at \|X\|32.15 - relieving that undercuts the bosses that
> just got fixed. So: use the top-middle header, and say whether the left one can be
> desoldered.

### Joystick (KY-023)

| # | What | Why it matters | Current assumption |
| --- | --- | --- | --- |
| 6 | Stick **pivot centre** offset from the PCB centre, both axes | sets where the rump bore goes. The 4 holes are offset toward the header, so the gimbal is probably not centred | assumed centred on the **hole pattern** |
| 7 | ~~Which edge is the 5-pin header on, and how far does it stand proud?~~ | **ANSWERED 2026-08-24**: on a SHORT edge, extending the 32.30 length to ~37.5 overall, raised ~5 mm and bent parallel to the board. The insertion channel now has a dedicated pin step (`joy_pin_chan_w`, 45.7 wide, to Y-53) that clears it on either side | measured |
| 8 | Which axis carries the gimbal's **23.40** nub (vs 19.80)? | the insertion channel's outer step is 27.4 across X; the wide axis must go across X | assumed nub on the X axis |
| 9 | PCB corner -> nearest hole centre | how much can be trimmed if it ever needs to be | - |

> Items 7 and 8 got much cheaper with the re-fit. There is no pocket and no bore any
> more, so a proud header no longer has to be desoldered - it just has to clear the
> rump channel.

### The cage you already printed

| # | What | Why it matters |
| --- | --- | --- |
| 10 | Measured outer size vs nominal **75.0 x 80.0 x 88.0** | if the printer is running small or large, that error stacks on top of every fit above, and it is worth knowing before another long print |

> That printed cage is the **160 mm** design (75 x 78 x 60). It is superseded - the
> host is now 200 mm and the box is 28 mm deeper. Its dimensional error is still
> worth measuring, because the printer's scaling carries over.

---

## When you're done

Paste the numbers back in any format - the filled tables, or just a list. I will
update `dimensions.scad`, work out the derived values (`oled_active_dx`/`dy`,
`joy_throw_a`), add the new variables that have no home yet, and flag anything
that looks off against the nominal figures.

If a part turns out very different from nominal, say so rather than assuming you
mismeasured - clones genuinely do vary, and a surprise is worth a second look
before it becomes a printed part.

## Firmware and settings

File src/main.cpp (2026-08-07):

/*
 * Vocetempo - a standalone talking bedside clock.
 *
 * -------------------------------------------------------------------------
 * The app is a small state machine with two views:
 *   - Clock view: shows the time, speaks on demand, auto-announces, and plays
 *                 a playful panda reaction on the arrow buttons.
 *   - Menu view : configure interval, quiet hours, volume, time, date, format,
 *                 language.
 *
 * Input is a single KY-023 thumbstick. Buttons.h maps it to four logical
 * actions - stick up/down, left = BACK, right or a press = OK - so everything
 * below is written in terms of those actions, not the hardware.
 *
 * Controls (clock view):
 *   - BACK  (stick left)        : tap speaks the current time, hold mutes.
 *   - OK    (press or right)    : open the settings menu.
 *   - UP/DOWN                   : panda reaction animation (eye-candy).
 * Controls (menu view): UP/DOWN navigate (hold to repeat), OK select/confirm,
 *   BACK go back/exit.
 *
 * Settings persist in flash (NVS) and are reloaded at boot. A panda-themed
 * animated splash plays at startup.
 *
 * Wiring: see docs/WIRING.md.
 */

#include <Arduino.h>
#include <esp_task_wdt.h>

#include "Announcer.h"
#include "Audio.h"
#include "Buttons.h"
#include "Display.h"
#include "Menu.h"
#include "RealtimeClock.h"
#include "Settings.h"
#include "Localization.h"

// Stage 12: soak-test aids.
// Watchdog: if the loop ever hangs longer than this, the chip auto-resets.
static const uint32_t WDT_TIMEOUT_S = 30;
// Heartbeat: print uptime + free heap this often, to catch leaks/resets.
static const unsigned long HEARTBEAT_MS = 60000;

static const uint8_t LED_PIN = 2;

static Display display;
static RealtimeClock clock_;
static Audio audio;
static Buttons buttons;
static Announcer announcer;
static Settings settings;
static Menu menu(display, settings, announcer, clock_);

static uint8_t lastSecond = 255;
static bool audioReady = false;

// Remembers if OK was the button that interrupted speech, so the main loop can
// still act on it (open the menu) without needing a second press.
static bool pendingOpenMenu = false;

// Interrupt check for Audio: returns true if the user presses any button
// during speech, so playback aborts and the UI stays responsive.
bool anyButtonInterrupt() {
  buttons.update();
  bool ok = buttons.wasPressed(Button::Ok);
  bool other = buttons.wasPressed(Button::Back) ||
               buttons.wasPressed(Button::Up) ||
               buttons.wasPressed(Button::Down);
  if (ok) pendingOpenMenu = true;  // carry the intent out to the main loop
  return ok || other;
}

void speakNow() {
  if (!audioReady) return;
  uint16_t yr;
  uint8_t mo, dy, hh, mm, ss, wd;
  if (clock_.now(yr, mo, dy, hh, mm, ss, wd)) {
    Serial.print(F("Speaking: "));
    Serial.print(hh);
    Serial.print(':');
    Serial.println(mm);
    audio.speakTime(hh, mm, settings.use24h, languageOffset(settings.language));
  }
}

void setup() {
  Serial.begin(115200);
  delay(500);

  pinMode(LED_PIN, OUTPUT);

  Serial.println();
  Serial.println(F("========================================"));
  Serial.println(F("  Vocetempo - panda-themed talking clock"));
  Serial.println(F("========================================"));

  if (display.begin()) {
    Serial.println(F("OLED initialised OK."));
    display.showBootSplash();  // panda-themed animated splash
  } else {
    Serial.println(F("ERROR: OLED not found."));
  }

  bool rtcReady = clock_.begin();
  if (rtcReady) {
    Serial.println(F("DS3231 RTC initialised OK."));
  } else {
    Serial.println(F("ERROR: DS3231 RTC not found."));
  }

  // Load persisted settings (or defaults on first boot).
  settings.load();

  // The DST zone must be applied BEFORE any clock read or write, because it
  // decides how the RTC's stored standard time is interpreted. Seeding from
  // compile time below is a write, so it has to come after this.
  clock_.setDstZone(settings.dstZone);
  if (settings.dstZone != DstZone::Off) {
    Serial.print(F("DST zone: "));
    Serial.print(dstZoneName(settings.dstZone));
    Serial.println(clock_.dstActive() ? F(" (summer time active)")
                                      : F(" (standard time)"));
  }

  if (rtcReady) {
    // Only auto-set the clock if power was *really* lost (debounced across
    // several reads + corroborated by an invalid time). This prevents a
    // glitching I2C bus from tricking us into overwriting a clock that is
    // actually keeping good time. Deliberate time changes go through the menu.
    if (clock_.powerReallyLost()) {
      Serial.println(F("RTC power was lost; seeding from compile time."));
      clock_.setToCompileTime();
    }
  }

  if (audio.begin()) {
    audioReady = true;
    audio.setVolume(settings.volume);
    audio.setInterruptCheck(anyButtonInterrupt);  // press a button to stop speech
    Serial.println(F("DFPlayer initialised OK."));
  } else {
    Serial.println(F("WARNING: DFPlayer not responding."));
  }

  buttons.begin();
  // Report the stick's measured resting point. If calibration was rejected the
  // user was probably holding it at boot, or an axis is not connected - either
  // way the deadzone falls back to nominal and the log says so rather than
  // leaving a mystery. tools/joystick_test gives the full picture.
  Serial.print(F("Joystick centre: x="));
  Serial.print(buttons.centreX());
  Serial.print(F(" y="));
  Serial.print(buttons.centreY());
  if (buttons.calibrated()) {
    Serial.println(F(" (calibrated)"));
  } else {
    Serial.print(F(" (NOT calibrated - resting read x="));
    Serial.print(buttons.rawX());
    Serial.print(F(" y="));
    Serial.print(buttons.rawY());
    Serial.println(F("; stick held at boot or an axis unwired?)"));
  }

  // Apply loaded settings to the announcer.
  announcer.setInterval(settings.interval);
  announcer.setQuietHours(settings.quietEnabled, settings.quietStartH,
                          settings.quietStartM, settings.quietEndH,
                          settings.quietEndM);

  // Stage 12: enable the task watchdog on the loop task. If loop() ever fails
  // to check in within WDT_TIMEOUT_S, the chip resets and recovers on its own.
  esp_task_wdt_init(WDT_TIMEOUT_S, /*panic=*/true);
  esp_task_wdt_add(NULL);  // watch the current (loop) task

  Serial.println(F("Ready. Stick LEFT taps to speak, hold to mute; press or "
                   "RIGHT opens the menu; UP/DOWN pet the panda."));
  Serial.print(F("Soak test: watchdog "));
  Serial.print(WDT_TIMEOUT_S);
  Serial.println(F("s, heartbeat every 60s."));
}

// How long BACK must be held (ms) on the clock face to toggle mute.
static const unsigned long MUTE_HOLD_MS = 800;
// How long the interactive panda screen waits with no input before returning.
static const unsigned long PANDA_IDLE_TIMEOUT_MS = 6000;

// Interactive "pet the panda" screen. Stays up reacting to buttons: UP waves
// the right paw, DOWN the left, OK a happy bounce; each pet adds a heart (max
// 5). The panda blinks on its own while idle. Returns on BACK or after a few
// seconds of no input. Blocking, but feeds the watchdog throughout.
static void runPandaMode(bool startWaveRight) {
  // A few rotating captions so repeated petting stays fun.
  static const char* const kPetCaptions[] = {"Hi!", "Hehe", "Yay!", "Boop",
                                              "Panda!"};
  static const uint8_t kNumCaptions = 5;

  uint8_t hearts = 1;
  uint8_t capIdx = 0;
  // Paw side follows the direction pushed: UP -> left paw, DOWN -> right paw.
  // `startWaveRight` is true when entered via UP; we invert it here so the
  // waving paw matches the way the stick was moved.
  Panda::Pose pose = startWaveRight ? Panda::Pose::WaveLeft
                                    : Panda::Pose::WaveRight;

  unsigned long lastInteract = millis();
  unsigned long lastBlink = millis();

  display.showPandaFrame(pose, hearts, kPetCaptions[capIdx]);

  while (true) {
    buttons.update();
    esp_task_wdt_reset();

    bool up = buttons.wasPressed(Button::Up);
    bool down = buttons.wasPressed(Button::Down);
    bool ok = buttons.wasPressed(Button::Ok);
    bool back = buttons.wasPressed(Button::Back);

    if (back) break;  // BACK leaves the panda screen

    if (up || down || ok) {
      lastInteract = millis();
      if (hearts < 16) hearts++;  // matches Display's side-column heart layout
      capIdx = (capIdx + 1) % kNumCaptions;
      // UP -> left paw, DOWN -> right paw (mirrors the stick's movement).
      if (up) pose = Panda::Pose::WaveLeft;
      else if (down) pose = Panda::Pose::WaveRight;
      else pose = Panda::Pose::Happy;

      // A quick two-step bounce so the reaction feels lively, not static.
      display.showPandaFrame(pose, hearts, kPetCaptions[capIdx]);
      delay(120);
      display.showPandaFrame(Panda::Pose::Blink, hearts, kPetCaptions[capIdx]);
      delay(90);
      display.showPandaFrame(pose, hearts, kPetCaptions[capIdx]);
      lastBlink = millis();
    } else if (millis() - lastBlink > 2500) {
      // Idle blink to keep the panda feeling alive.
      lastBlink = millis();
      display.showPandaFrame(Panda::Pose::Blink, hearts, "");
      delay(120);
      display.showPandaFrame(Panda::Pose::Happy, hearts, "");
    }

    if (millis() - lastInteract > PANDA_IDLE_TIMEOUT_MS) break;
    delay(10);
  }

  lastSecond = 255;      // force a clock redraw when we return
  esp_task_wdt_reset();
}

// Stage 12: heartbeat - print uptime, free heap, and the RTC time so a soak log
// shows liveness, memory stability, and clock accuracy over time.
//
// Called from the TOP of loop(), before the menu early-return, so a clock left
// sitting in a menu overnight still proves it is alive. With this at the bottom
// of loop() the log went completely silent whenever a menu was open, which is
// indistinguishable from a crash in a soak log.
static void heartbeat() {
  static unsigned long lastBeat = 0;
  if (millis() - lastBeat < HEARTBEAT_MS) return;
  lastBeat = millis();
  Serial.print(F("[hb] up="));
  Serial.print(millis() / 1000);
  Serial.print(F("s heap="));
  Serial.print(ESP.getFreeHeap());
  Serial.print(F(" rtc="));
  Serial.println(clock_.timeString(true));
}

void loop() {
  buttons.update();
  heartbeat();

  if (menu.isActive()) {
    // ---- Menu view ----
    menu.handle(buttons);

    // When the menu exits, re-apply volume (it may have changed) and force a
    // clock redraw.
    if (!menu.isActive()) {
      audio.setVolume(settings.volume);
      lastSecond = 255;
    }
    // The menu is a legitimately long-lived state - a user can sit on a screen
    // for minutes - so it must feed the watchdog itself. This return skips the
    // reset at the bottom of loop(), so without this line the 30s watchdog
    // could reset the clock while someone was simply reading a settings page.
    esp_task_wdt_reset();
    delay(5);
    return;
  }

  // ---- Clock view ----

  // If OK was pressed to interrupt speech, honour that intent now by opening
  // the menu (no second press needed).
  if (pendingOpenMenu) {
    pendingOpenMenu = false;
    menu.open();
    delay(5);
    return;
  }

  // BACK: a short tap speaks the time; a long hold toggles mute. We track the
  // press here and act either when the hold threshold is crossed (mute) or on
  // release before that (speak). Booleans below are read once each - remember
  // wasPressed() consumes the edge.
  static bool backHolding = false;      // BACK is currently held down
  static bool backHoldHandled = false;  // the hold already toggled mute
  static unsigned long backPressStart = 0;

  if (buttons.wasPressed(Button::Back)) {
    backHolding = true;
    backHoldHandled = false;
    backPressStart = millis();
  }
  if (backHolding) {
    if (buttons.isDown(Button::Back)) {
      // Still held: has it crossed the mute-toggle threshold?
      if (!backHoldHandled && millis() - backPressStart >= MUTE_HOLD_MS) {
        backHoldHandled = true;
        settings.muted = !settings.muted;
        settings.save();
        Serial.print(F("Mute toggled -> "));
        Serial.println(settings.muted ? F("MUTED") : F("unmuted"));
        // On-theme confirmation: the panda covers its ears (blink) when muted,
        // or waves happily when unmuted.
        display.showPandaFrame(
            settings.muted ? Panda::Pose::Blink : Panda::Pose::Happy, 0,
            tr(settings.muted ? Str::Muted : Str::SoundOn, settings.language));
        delay(900);
        lastSecond = 255;  // redraw clock (with/without mute icon) next tick
        esp_task_wdt_reset();
      }
    } else {
      // Released. If the hold never toggled mute, treat it as a tap -> speak.
      backHolding = false;
      if (!backHoldHandled) speakNow();
    }
  }

  if (buttons.wasPressed(Button::Ok)) {
    menu.open();
    delay(5);
    return;  // start the menu cleanly next loop (no leaked events)
  }

  // UP / DOWN on the clock face open the interactive "pet the panda" screen.
  // Read each edge once into a local first: wasPressed() consumes the edge.
  bool upPressed = buttons.wasPressed(Button::Up);
  bool downPressed = buttons.wasPressed(Button::Down);
  if (upPressed || downPressed) {
    runPandaMode(/*startWaveRight=*/upPressed);
  }

  if (audioReady) audio.pollStatus();

  uint16_t year;
  uint8_t month, day, hour, minute, second, weekday;
  bool haveTime = clock_.now(year, month, day, hour, minute, second, weekday);

  // I2C fault recovery: if time reads keep failing (a glitching bus/loose
  // wire), the RTC and OLED share the bus, so recover it instead of flooding
  // errors. After several consecutive bad reads, re-init the bus + display.
  static uint16_t badReads = 0;
  if (!haveTime) {
    badReads++;
    if (badReads >= 20) {  // ~ several hundred ms of failures
      Serial.println(F("I2C fault: attempting bus/display recovery..."));
      display.recover();
      badReads = 0;
    }
  } else {
    badReads = 0;
  }

  // Update the clock face FIRST, before any (blocking) announcement. Otherwise
  // speakTime() would hold the loop for the whole 5-10s phrase and the OLED
  // would only catch up to the new minute after the voice finished - so the
  // voice appeared to "run ahead" of the screen by several seconds.
  if (haveTime && second != lastSecond) {
    lastSecond = second;
    bool quiet = announcer.isQuietNow(hour, minute);
    // Weekday name is localized to the selected language (audio + on-screen
    // text stay in sync). We pass the raw day-of-week we already read.
    display.showClock(weekdayName(weekday, settings.language),
                      clock_.timeString(false), clock_.dateString(), quiet,
                      settings.muted);
    digitalWrite(LED_PIN, second % 2 ? HIGH : LOW);
  }

  // Automatic announcements at the configured interval (skipped in quiet hours
  // and when muted). shouldAnnounce() is asked on every good time read, even
  // while muted or without audio, so its once-per-boundary guard keeps
  // following the clock and cannot go stale; the checks below decide whether to
  // act on the answer. This runs AFTER the display update above so the screen
  // already shows the new time.
  bool announceDue = haveTime && announcer.shouldAnnounce(hour, minute, second);
  if (announceDue && audioReady && !settings.muted) {
    Serial.print(F("Auto-announcing: "));
    Serial.print(hour);
    Serial.print(':');
    Serial.println(minute);
    audio.speakTime(hour, minute, settings.use24h,
                    languageOffset(settings.language));
  }

  // Feed the watchdog so it knows the loop is healthy.
  esp_task_wdt_reset();

  delay(5);
}

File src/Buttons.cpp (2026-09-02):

#include "Buttons.h"

// ---- Pins (see docs/WIRING.md) ----------------------------------------------
//
// The axes MUST be on ADC1 channels. ADC2 is unusable while Wi-Fi is active and
// is generally less well behaved on the ESP32; ADC1 is GPIO 32-39. GPIO 32/33
// are the two pins the UP/DOWN buttons used, so the joystick drops onto the
// existing wiring with nothing else to move.
//
// The switch needs an internal pull-up, which GPIO 34-39 do not have (they are
// input-only), so it goes on GPIO 25 - the pin the OK button used.
static const uint8_t kPinAxisX = 32;  // KY-023 VRx (ADC1_CH4)
static const uint8_t kPinAxisY = 33;  // KY-023 VRy (ADC1_CH5)
static const uint8_t kPinSwitch = 25;  // KY-023 SW, shorts to GND when pressed

// Axis orientation. Which way a pot swings depends on how the module ends up
// mounted, so these are the one thing to flip after assembly if the stick feels
// backwards. Confirm with `pio run -e joystick_test -t upload`, which prints the
// raw values and the decoded direction.
//
// X is inverted: the stick sits rotated relative to the earlier enclosure, so
// left/right came out swapped on the assembled unit. Y reads correctly as-is.
static const bool kInvertX = true;
static const bool kInvertY = false;

// Number of resting samples averaged at boot to find the stick's centre.
static const uint8_t kCalibrationSamples = 8;

// Simple, dependency-free debounce shared by every logical action. For each one
// we track the last stable state, the last raw reading, and when it last
// changed. The analog axes already have hysteresis, so this mostly matters for
// the mechanical switch - but running everything through one path keeps press
// edges and hold-to-repeat behaving identically whichever input produced them.
static const unsigned long kDebounceMs = 8;

static bool stablePressed[4];   // debounced "is pressed"
static bool lastRawPressed[4];  // previous raw reading
static unsigned long lastChange[4];
static bool pressedEdge[4];     // set on a fresh press, cleared by wasPressed()
static unsigned long pressStart[4];  // when the current press began
static unsigned long lastRepeat[4];  // last time repeat() fired for a hold

// Map the decoded stick direction plus the switch onto the four logical
// actions. OK deliberately has two sources: a right push and a press.
static void mapToActions(JoyDir dir, bool switchPressed, bool out[4]) {
  out[static_cast<uint8_t>(Button::Up)] = (dir == JoyDir::Up);
  out[static_cast<uint8_t>(Button::Down)] = (dir == JoyDir::Down);
  out[static_cast<uint8_t>(Button::Ok)] = (dir == JoyDir::Right) || switchPressed;
  out[static_cast<uint8_t>(Button::Back)] = (dir == JoyDir::Left);
}

void Buttons::begin() {
  pinMode(kPinSwitch, INPUT_PULLUP);
  // The axes are analog inputs; no pull-up, or it would fight the pot divider.
  pinMode(kPinAxisX, INPUT);
  pinMode(kPinAxisY, INPUT);

  _joystick.setInvert(kInvertX, kInvertY);

  // Calibrate the deadzone against where this particular stick actually rests,
  // rather than assuming a perfect midpoint.
  uint32_t sumX = 0, sumY = 0;
  for (uint8_t i = 0; i < kCalibrationSamples; i++) {
    sumX += analogRead(kPinAxisX);
    sumY += analogRead(kPinAxisY);
    delay(2);
  }
  const uint16_t avgX = sumX / kCalibrationSamples;
  const uint16_t avgY = sumY / kCalibrationSamples;

  // Only trust the sample if it looks like a centred stick. If the user happens
  // to be holding it at boot - or an axis is unplugged and reading a rail -
  // baking that in would bias the deadzone for the whole session and could leave
  // a direction permanently engaged.
  _calibrated = Joystick::centreIsPlausible(avgX, avgY);
  if (_calibrated) {
    _joystick.setCentre(avgX, avgY);
  }
  _rawX = avgX;
  _rawY = avgY;

  // Seed the debounce state from the current reading so a stick held at boot
  // does not register as a fresh press on the first update().
  bool raw[4];
  mapToActions(_joystick.update(avgX, avgY), digitalRead(kPinSwitch) == LOW, raw);
  for (uint8_t i = 0; i < kCount; i++) {
    stablePressed[i] = raw[i];
    lastRawPressed[i] = raw[i];
    lastChange[i] = millis();
    pressedEdge[i] = false;
  }
}

void Buttons::update() {
  const unsigned long now = millis();

  // One read per axis per call. The hysteresis in Joystick makes averaging
  // unnecessary, and update() runs from inside audio playback too, so keeping it
  // cheap matters.
  _rawX = analogRead(kPinAxisX);
  _rawY = analogRead(kPinAxisY);
  const JoyDir dir = _joystick.update(_rawX, _rawY);
  const bool switchPressed = (digitalRead(kPinSwitch) == LOW);

  bool raw[4];
  mapToActions(dir, switchPressed, raw);

  for (uint8_t i = 0; i < kCount; i++) {
    if (raw[i] != lastRawPressed[i]) {
      // Raw reading changed - restart the debounce timer.
      lastRawPressed[i] = raw[i];
      lastChange[i] = now;
    } else if (now - lastChange[i] >= kDebounceMs) {
      // Reading has been stable long enough - accept it.
      if (raw[i] != stablePressed[i]) {
        stablePressed[i] = raw[i];
        if (raw[i]) {
          // Transitioned to pressed: record a press edge.
          pressedEdge[i] = true;
          pressStart[i] = now;
          lastRepeat[i] = now;
        }
      }
    }
  }
}

bool Buttons::wasPressed(Button b) {
  uint8_t i = static_cast<uint8_t>(b);
  if (i >= kCount) return false;
  if (pressedEdge[i]) {
    pressedEdge[i] = false;  // consume the edge
    return true;
  }
  return false;
}

bool Buttons::repeat(Button b, unsigned long firstDelayMs,
                     unsigned long intervalMs) {
  uint8_t i = static_cast<uint8_t>(b);
  if (i >= kCount) return false;

  // Fire immediately on the initial press edge.
  if (pressedEdge[i]) {
    pressedEdge[i] = false;
    lastRepeat[i] = millis();
    return true;
  }

  // While held, fire repeatedly after the initial delay.
  if (stablePressed[i]) {
    unsigned long now = millis();
    if (now - pressStart[i] >= firstDelayMs &&
        now - lastRepeat[i] >= intervalMs) {
      lastRepeat[i] = now;
      return true;
    }
  }
  return false;
}

bool Buttons::isDown(Button b) {
  uint8_t i = static_cast<uint8_t>(b);
  if (i >= kCount) return false;
  return stablePressed[i];
}

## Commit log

2026-07-22 Stage 1: project scaffold + ESP32 serial hello
    Set up PlatformIO project for the DollaTek ESP32 (esp32dev), add a minimal
    serial heartbeat + onboard LED blink to verify the toolchain, and document
    the full hardware map and 12-stage roadmap in docs/PLAN.md.
2026-07-22 Stage 2: OLED display over I2C
    Add Adafruit GFX/SSD1306 libraries and a modular Display class wrapping the
    SSD1309 panel (confirmed at I2C address 0x3C). main.cpp now initialises the
    display and shows a splash screen. Add a dual-orientation I2C scanner tool in
    its own build environment for hardware bring-up/debugging.
2026-07-28 Stage 3: read DS3231 time and render live clock on OLED
    Add RTClib and a modular RealtimeClock class wrapping the DS3231 (0x68).
    main.cpp initialises the RTC, seeds it from compile time if power was lost,
    and draws a centred clock face (weekday / large HH:MM / date) that updates
    each second. Add a showClock() helper to Display and a full wiring reference
    in docs/WIRING.md covering all v1 components.
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2026-07-29 Stage 7: four debounced buttons (UP/DOWN/OK/BACK)
    Add a modular Buttons class reading GPIO 32/33/25/26 as active-low with
    internal pull-ups. Uses a small built-in debounce instead of Bounce2, which
    was not reading reliably on this ESP32/version. main.cpp shows the pressed
    button on the OLED and speaks the test clip on OK. Add a button_test
    diagnostic env. Document the DFPlayer mono/BTL speaker wiring in WIRING.md
    after diagnosing an overheating amp caused by shorting SPK1+SPK2 to GND.
    [Buttons.cpp, button_test.cpp, main.cpp]
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2026-07-29 Stage 12: add task watchdog + uptime/heap heartbeat for soak testing
    Enable the ESP32 task watchdog (30s) on the loop task so the clock
    auto-recovers from any hang, and print a heartbeat every 60s with uptime,
    free heap, and RTC time to detect leaks, resets, or clock drift during a
    long-run soak test. Ignore the local soak/ log directory.
    [main.cpp]
2026-07-29 Add multi-language speech: English, Portuguese-PT, Spanish
    The DFPlayer clone only supports playMp3Folder(n) (folder addressing via
    playFolder/playLargeFolder does not work - verified on hardware with a
    folder_test diagnostic). So all languages live in /mp3 using per-language
    index offsets: EN 0001-1440, PT 2001-3440, ES 4001-5440.
    Add generate_multilang.py (parallel TTS with per-language grammar and
    accented text: PT E/Sao, ES Es la/Son las; voices Joana and Paulina) and fix
    the silence-trim filter so long phrases are no longer cut off (regenerated
    English too). Add a Language setting persisted in NVS, a Language menu item,
    and a langOffset parameter to Audio::speakTime. 4320 phrase files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
    [Audio.cpp, folder_test.cpp]
2026-07-30 Add I2C fault resilience + OLED panel diagnostic
    Harden against the intermittent I2C bus faults seen during the soak test
    (garbled OLED + Wire error flood after a wire glitch):
    - Display: set a 50ms Wire timeout so a wedged bus returns errors instead of
    blocking the loop; add recover() to re-init Wire + the panel after a fault.
    - RealtimeClock: reject invalid/out-of-range RTC reads (isValid + bounds) so a
    glitched read never drives the UI or triggers a wrong announcement.
    - main: after repeated failed time reads, attempt display/bus recovery.
    - Add an oled_test diagnostic that force-lights the panel (DISPLAYALLON) to
    distinguish a dead panel from a software/init issue.
    Note: current O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
    [Display.cpp, main.cpp, oled_test.cpp]
2026-07-30 Add panda theme, mute toggle, and fix announcement bugs
    - Panda mascot (Panda module, GFX-drawn poses) with animated boot
    splash and an interactive "pet the panda" screen on UP/DOWN
    (waving paws matched to button side, hearts filling the sides,
    idle blink, auto-exit).
    - Mute: hold BACK on the clock face to toggle; suppresses automatic
    announcements only (manual speak still works), shows a mute icon,
    persists in NVS.
    - Harden RTC boot auto-write: powerReallyLost() debounces the
    power-loss flag across reads + corroborates with a valid time, so
    an I2C glitch can never overwrite a good clock.
    - Fix voice running ahead of the screen: redraw the clock before the
    blocking announceme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
    [Audio.cpp, Display.cpp]
2026-07-31 Localize on-screen text to the selected language
    Changing the language now switches the UI text as well as the audio:
    weekday name, the Muted/Sound on caption, and every menu label, value
    and hint follow EN/PT/ES via a new Localization module (one Str enum +
    a per-language table). Weekday handling moved out of RealtimeClock so
    the raw day-of-week is localized at the call site.
    On-screen strings are intentionally ASCII (accent-free) because the
    Adafruit GFX default font only renders ASCII reliably; the spoken audio
    keeps full accented pronunciation. The module is named Localization,
    not Strings, to avoid clashing with <string.h> on case-insensitive
    filesystems.
    [main.cpp]
2026-07-31 Add parametric OpenSCAD panda enclosure concepts
    Exploratory sitting-panda enclosure concepts (massing models) in
    OpenSCAD, sharing one dimensions/helpers library. Includes three
    geometric takes plus concept 4, an organic waving/holding baby panda
    based on a MakerWorld reference, cradling the OLED on its belly. A
    render script and README document how to preview and the intended
    serviceability (socketed DFPlayer above a bottom SD hatch).
    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
    [concept1_chubby_panda.scad, concept2_box_panda.scad, concept3_minimal_panda.scad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]
2026-08-07 Add joystick controls, Controls page, and reliability fixes
    - Replace 4 push buttons with a KY-023 analog joystick (Buttons/Joystick)
    - Add a localized Controls reference page in the settings menu
    - Move heartbeat above the menu early-return and feed the watchdog in the
    menu path (menus no longer silence the soak log or risk a WDT reset)
    - Ignore DFPlayer status 11 (routine command ACK) instead of logging it
    - Add DST handling (Dst.h) and RTC refinements
    - Update README/PLAN/WIRING for the joystick and USB-C
    [Audio.cpp, Buttons.cpp, Display.cpp]
2026-08-07 Record real caliper measurements and enclosure decisions
    - docs/MEASUREMENTS.md: full measurement method + every measured value
    (calibration via header plastic base, edge-to-hole spacing trick, OLED
    lit-area technique)
    - dimensions.scad: replace nominal values with measured ones for OLED, ESP32,
    joystick, RTC, DFPlayer, speaker (now a boxed unit, not a bare driver)
    - Design decisions: no perfboard (direct standoff mounting), sled-top speaker
    firing into the head, magnet-pair retention, USB-C exits back slot, panda
    rescaled to 160mm; cage envelope ~75x96x38
    - docs/ASSEMBLY.md updates to match
    [dimensions.scad]
2026-08-07 Add printable electronics cage; remove concept sculpts
    - cage.scad: complete print-ready cage (shell + OLED window + joystick cone +
    speaker throat + back-wall mounts + magnet flange + USB exit slot). Manifold,
    exports clean STLs via a part selector (cage / esp32_bar / dfp_bar).
    - layout_backwall.scad: 2D collision-check map of the back-wall board layout
    - Remove concept1-4 sculpts and their previews (superseded by the cage)
    - Update README + render_previews.sh for the cage; gitignore generated STLs
    [cage.scad, concept1_chubby_panda.scad, concept2_box_panda.scad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]
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2026-08-07 Add panda body hollowing + retarget cage to belly spacing (WIP)
    - panda.scad: import + scale (166.7 -> 160mm) + prism cavity + opening cuts;
    the sculpt already has a screen + knob on the belly and a round head, so we
    cut the OLED window / joystick cone / speaker neck bore through them
    - Discovered the belly can't fit the cage's stacked OLED+joystick (36mm); the
    sculpted features sit ~28mm apart. Retarget: OLED and joystick centres now
    28mm apart, boards overlap in Z at different standoff depths
    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
    [cage.scad, dimensions.scad, panda.scad]
2026-08-07 Re-layout cage back wall for the shorter 78mm cage
    - Joystick standoff back to shallow 6mm (the 16mm deep offset had pushed its
    pins into the back-wall boards); OLED and joystick components clear without it
    - Back wall re-laid out and collision-checked: ESP32 portrait full-height left,
    RTC top-right, DFPlayer bottom-right - all in bounds, no overlaps
    - Cage exports manifold (Simple: yes)
    [cage.scad, layout_backwall.scad]
2026-08-07 Solve panda booleans via Manifold backend; slim printed joystick cap
    - ROOT CAUSE fixed: OpenSCAD 2021.01's CGAL couldn't boolean the 500k-tri panda
    (>15min). Upgraded to 2026.06 snapshot; --backend=Manifold does it in ~2s at
    full mesh detail. No decimation needed.
    - Fixed the cut extrude direction (was extruding OUT of the belly, not into it)
    - The stock 26mm joystick cap forced a ~32mm opening (nearly screen-sized). We
    now design a SLIM ~16mm printed replacement cap -> ~20mm opening, and used as a
    d-pad the stick needs only ~11deg travel. Lets OLED-joystick spacing drop to
    25mm. Recorded joy_slim_cap_d / joy_panel_open (shaft dims TODO-measure).
    - panda.scad cuts OLED window + jo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
    [dimensions.scad, panda.scad]
2026-08-07 Reconcile device placement + fix panda shoulder holes
    Single source of truth: dimensions.scad now holds dev_oled_pz/dev_joy_pz
    (panda-frame device centres) and derives dev_sep/oled_cz/joy_cz from them
    + cage_z0, so panda.scad and cage.scad can no longer drift apart. Placement
    is based on mesh analysis (screen plaque ~Z40, knob ~Z20) spread symmetric
    about the midpoint -> OLED window panda Z44, joystick Z16 (28mm apart).
    Fix the "shoulder holes": the old cavity was a tall full-width box that
    pierced the thin armpit walls where the folded arms leave a gap. Replaced
    with a TAPERED cavity (full-width low for the OLED+boards, narrowing toward
    the top to stay inside the narrowing torso). Verified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
    [cage.scad, dimensions.scad, layout_backwall.scad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]
2026-08-07 Fix speaker sound path: connect cavity to head via neck chimney
    The old panda_neck_bore was a cylinder at Z88..128 that never reached the
    cavity top (Z64) or the speaker on the cage top (Z80) - an 8-16mm plug of
    solid body blocked the sound entirely (seen in a section render).
    Replaced with a chimney that OVERLAPS the cavity (starts Z55, below the
    cavity top) and rises to Z118 into the hollow head, so the void is
    continuous: speaker (cage top) -> neck -> head resonator. Sized 48x34
    (clears the 37.35x26.80 grille), centred on the neck's solid mid-Y, kept
    narrow enough to stay inside the leaning neck. Verified connected and
    breach-free by render + section. Head vents retargeted but left out o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
    [panda.scad]
2026-08-10 Deepen cage to reach the belly (fix OLED-in-a-tunnel)
    Integration fit-check exposed a major flaw: the panda belly bulges ~86mm
    forward of the body centre, so the shallow 38mm cage left the OLED at the
    bottom of a deep dark tunnel. Deepened the cage to 80mm (cage_d) so its
    front (OLED/joystick) face sits ~7-13mm behind the belly (a shallow
    recessed screen) while the back wall (ESP32/RTC/DFPlayer) sits near the
    torso rear. The torso has room (~95-107mm deep through this region).
    Added cage_yfront/cage_yc as the panda-Y placement (front face at Y54,
    centre Y14). Documented the placement transform (cage is rotated 180 about
    Z then translated, since cage.scad's own frame puts the OLED front at -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
    [dimensions.scad, panda.scad]
2026-08-10 Taper cage top to the shoulders + add fit-check tooling
    The panda torso is round and narrows at the shoulders, so the deep cage's
    top corners poked through. Replaced the plain box top with a TAPER above
    Z62 to a smaller speaker platform (70x50, shifted toward the belly where
    the torso is deeper). Clears the ear-boss span (63.6mm, diagonal 33.5 <
    torso 43) while tucking the top corners inside. Cage still exports as a
    clean manifold.
    Added enclosure/fitcheck.scad: places the cage in the panda via the
    documented transform (spin 180, translate to cage_yc/cage_z0) with ghost /
    section / breach modes, and wired two fitcheck renders into
    render_previews.sh. Section confirms OLED-at-belly, centred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
    [cage.scad, fitcheck.scad]
2026-08-10 Reshape base flange + magnets to the panda base (no belly-front overhang)
    With the deep cage, the old full-skirt flange put its two FRONT magnets out
    past the belly base (no body to seat on) - they landed outside the panda.
    Reshaped the flange: full outward rim at the BACK and SIDES (which sit over
    solid body base), flush with the wall at the belly FRONT. Moved the 4 magnet
    pockets to the two back corners + two mid-side positions, all over solid
    body. Cage still exports as a clean manifold. Cage-outside-panda breach down
    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
    [cage.scad]
2026-08-10 Add slim printed joystick cap (keyed oval press-fit)
    Measured the stock KY-023 shaft (rubber cap off): an oval post 4.0mm across
    the round x 3.0mm across two flats, 5.95mm tall. Recorded as joy_shaft_d /
    joy_shaft_w / joy_shaft_len.
    Added joy_cap() to cage.scad's part selector: a 16mm domed thumb-cap with a
    keyed OVAL socket that press-fits the shaft (the flats stop it rotating) and
    a mouth chamfer to guide it on; a drop of CA locks it. This keeps the panel
    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
    [cage.scad, dimensions.scad]
2026-08-10 Fix cage/panda orientation and re-fit the shell to the belly
    The panda sculpt's belly/face is at -Y (the smooth back is +Y); panda.scad
    had wrongly assumed "belly = +Y", so the OLED window and joystick opening were
    cut through the smooth BACK instead of the screen plaque and knob. panda_raw()
    now reorients the sculpt (180 about Z + Y shift) so the belly lands at +Y, and
    the joystick is placed on the knob (dev_joy_pz 14 -> 20).
    Rebuild the shell as a profile-driven "loaf" (shell_prof, shared by cage.scad and
    panda.scad via helpers.scad): flat, full walls through the whole board-mounting
    zone so every boss lands on a real flat wall, with corner-only chamfers where
    there are no features. The f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
    [cage.scad, dimensions.scad, fitcheck.scad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]
2026-08-11 Move the ear grille onto the inner-ear dish; fix + bevel the OLED window
    The ear vents were 2x3 bores drilled into each ear's outer-lower CORNER, which
    read as damage rather than a grille. Located the sculpted inner-ear dish properly
    instead: a density + surface scan of the 500k mesh (run per ear, since the stipple
    is randomised per side, then the two masks intersected so one layout is valid on
    both) puts it at a tilted oval, centre (X 40.1, Z 146.7), major axis -46.2 deg in
    XZ, ~20 x 13.8mm, recessed ~1.3mm behind the ear rim. Watch out when probing it:
    the stipple patch is a SEPARATE overlapping shell, so it emits rear-facing
    triangles at Y~21 and the ear's real back skin is only the geome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
    [cage.scad, dimensions.scad, helpers.scad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]
2026-08-11 Shorten the arms off the screen; give the magnets a body-side half
    ARMS. The window's side edges were cutting ~8mm into each folded paw, leaving a
    10mm-deep slice wall; bevelling only softened it. Shorten the arms instead, by
    intersecting the body with a copy of the SCULPT ITSELF shifted outboard by
    arm_shift. Where the shifted copy is less proud the arm is trimmed, where it is
    more proud nothing happens, so each arm's inboard flank retreats wearing its own
    natural end shape. Raycast says the worst overlap was 7.7mm at Z49..54, so
    arm_shift 9 lands the tip on the window edge: the skin just outside the aperture
    is now Y54 against a plaque face of Y52.4..53.6, i.e. a 0.4..2.2mm step instead of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
    [cage.scad, dimensions.scad, helpers.scad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]
2026-08-11 Shift the arm trim along the arm's axis, killing the pointed beak
    The floor plane was the problem. Restricting the trim to skin proud of Y54 kept
    the straight-outboard shift from trenching the creases, but where the shifted skin
    fell below that floor the cut bottomed out FLAT - leaving a plateau up to 9mm wide
    (measured: X-33..-25 at Z59..61) with a 4mm cliff on its inboard side where the
    belly drops away into the armpit. Seen from the front that plateau and its cliff
    read as a pointed beak sticking up above each paw.
    Fixed by shifting along the arm's OWN AXIS instead of straight outboard. The arm
    runs diagonally from the shoulder (X-40,Z68) down to the paw (X-20,Z50), so a shift
    along that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
    [panda.scad]
2026-08-12 Roll the paw tips off the screen edge; drop the window bevel
    The window bevel was the wrong tool. oled_bevel_* flared the whole aperture 5mm
    outward wherever the skin bulged past Y58, which turned the paw slice into a ~35deg
    bevel but left two flat "wings" either side of the screen, each ending in a hard
    crescent line across the paw. Combined with the axis-shifted arm_trim raking the
    arm's whole flank, the arms read as damaged rather than shortened.
    What the arms actually are, from a fresh scan of the 500k mesh: at screen height
    they ARE the body's flank. The front profile at Z56 climbs smoothly from Y38.7 at
    X-52 to the paw crest Y61.5 at X-28 with no crease anywhere, i.e. there is no bell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
    [panda.scad]
2026-08-13 Size the OLED window to the sculpt's embossed screen
    The sculpt already has a screen: a raised frame ~1mm proud enclosing the flat
    embossed plaque. Measured on panda_original.stl, its flat interior is
    36.4 x 22.05mm (Z35.2..57.25; |X| 18.20 on the tight side, 19.05 on the other
    - the sculpt sits ~0.4mm off-centre). The window is now oled_win_w x oled_win_h
    = 36 x 21mm, sized to sit just inside it, so the sculpted frame becomes the
    screen's bezel - plainly what it was modelled to be.
    This replaces making room for a full-width 55.4mm window. The lit area is 55mm
    wide but the plaque only 36.4, so such a window overhangs by 9.5mm per side and
    lands on the folded paws (the paw's inboard edge rea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
    [dimensions.scad, panda.scad]
2026-08-13 Open the belly window to the full lit area; cut through the paws
    DECISION (user): every one of the 128x64 pixels must be visible. So the window
    goes back to the whole lit area + fit_gap (55.4 x 28.4) and the folded paws that
    stand in front of it are cut through. The cut takes 8.1mm off each paw over
    Z42..58, leaving a flat vertical face on each, so the arms end at the screen
    rather than reading as folded. That is the accepted trade.
    This supersedes the previous commit, which sized the window to the sculpt's own
    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
    [dimensions.scad, panda.scad]
2026-08-25 Re-fit the enclosure to a 200mm de-embossed host
    The 160mm layout was deadlocked and no amount of rearranging inside it helped:
    the belly pinches in above the folded arms at panda Z72, which capped cage_h at
    64 against the 61.2mm a portrait ESP32 needs, put the ESP32's USB-C mouth level
    with the cover ledge (so no straight plug could ever be used), and left the
    joystick's cap stalk longer than the rump it pokes through. The boards do not
    scale, so the sculpt's size IS the clearance budget - scale_sweep.py tabulates
    host height against every gate, and 200mm is the first that passes all of them.
    Every constant in dimensions.scad's placement blocks is re-solved against
    panda/panda_original_with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
    [cage.scad, dimensions.scad, helpers.scad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]
2026-09-02 Invert the joystick X axis to match the rotated stick
    Left/right come out swapped on the assembled enclosure. The stick moved to the
    outside of the back wall in c8c6de9, which turns the module round relative to
    where it sat before, so VRx now swings the opposite way for the same push. Set
    kInvertX = true; Y is unaffected and stays false.
    This is the case kInvertX exists for, so nothing else changes: Joystick::update()
    negates dx straight after subtracting the calibrated centre, before the deadzone
    and the dominant-axis latch, so the thresholds are untouched. pio test -e native
    passes 43/43, including test_invert_flips_axes.
    If the cause were crossed VRx/VRy wires instead, up/down would be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
    [Buttons.cpp]
2026-10-07 Deepen and smooth panda joystick insertion channel
    [dimensions.scad, panda.scad]
2026-10-08 Relieve the panda cage entrance near the feet
    Remove the inward entrance hook and add a tapered front lead-in while preserving the magnet supports and seated cage fit. Include insertion-sweep checks and comparison evidence; retain the documented higher corner interference.
    [dimensions.scad, panda.scad]
2026-10-08 Preserve the panda shape with minimal uniform enlargement
    Scale only the outer body to 108.7% while retaining the original cage and fixed hardware cuts. Add the matching longer joystick cap, clearance and wall-thickness checks, and archived design comparisons.
    [cage.scad, dimensions.scad, fitcheck.scad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]
2026-10-08 Align the body speaker inlet with the existing cage
    Clear the offset speaker throat into the neck chimney without changing the exterior or printed cage. Add the complete assembly alignment audit, cutout comparisons, and updated printing and assembly i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
    [cage.scad, compare_alignment.scad, dimensions.scad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]
2026-10-08 Add painted panda 3MF projects and full-body previews
    Save the black-and-white painting iterations and final Bambu/Orca project, including the latest paint touch-ups. Document the final file and archive previews and verification reports; confirm the sav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
    [panda_body_uniform_v8_black_white.3mf, panda_body_uniform_v8_black_white_detailed.3mf, panda_body_uniform_v8_black_white_full.3mf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]
